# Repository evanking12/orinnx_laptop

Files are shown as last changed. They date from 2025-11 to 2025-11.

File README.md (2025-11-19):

8-Layer High-Speed PCB | NVIDIA Jetson Orin NX | Full Custom Laptop Motherboard

Author: Evan King
Status:  Revision A — Routing Complete, Pre-Fabrication
Tech Stack: Altium Designer • Jetson Linux • dtc/dtcpp • LPDDR5 SoM • eDP • M.2 • DCDC/PDN

Top view:

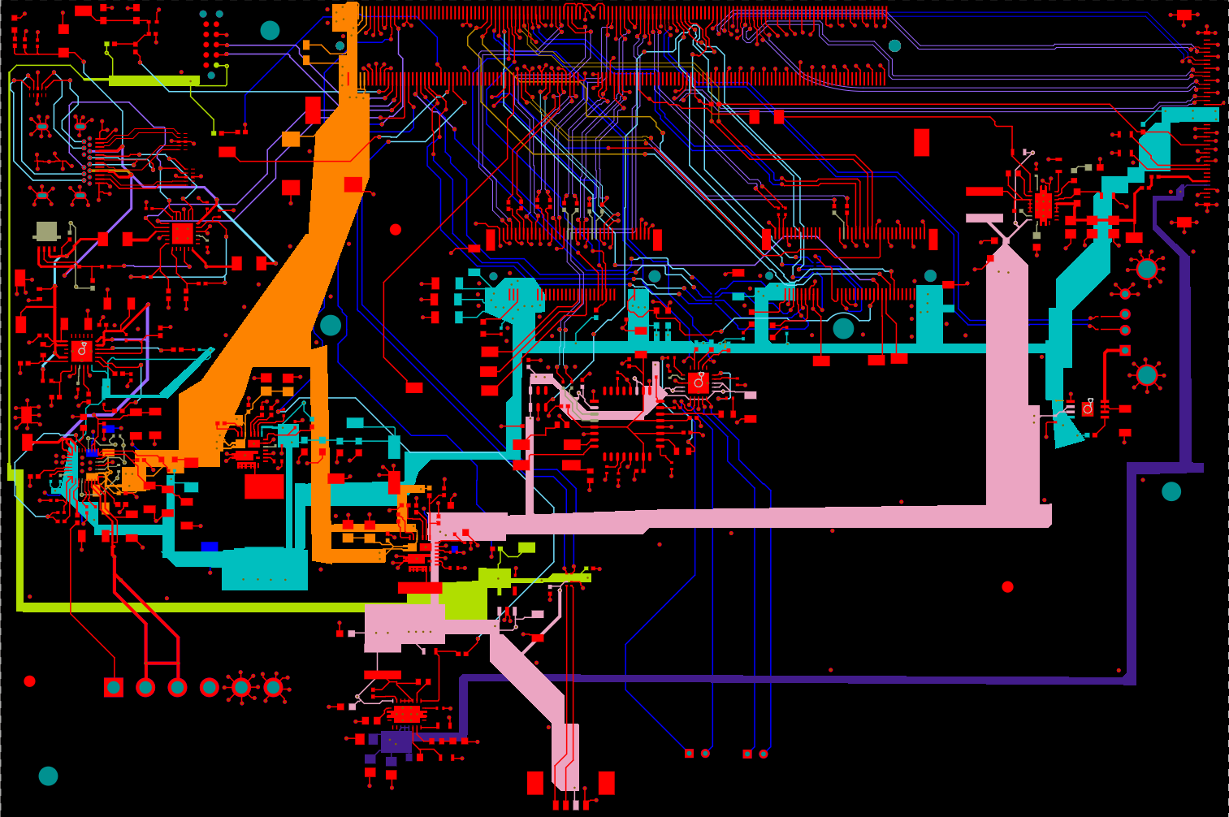
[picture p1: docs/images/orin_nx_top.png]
Orin NX Carrier Top


3D view:

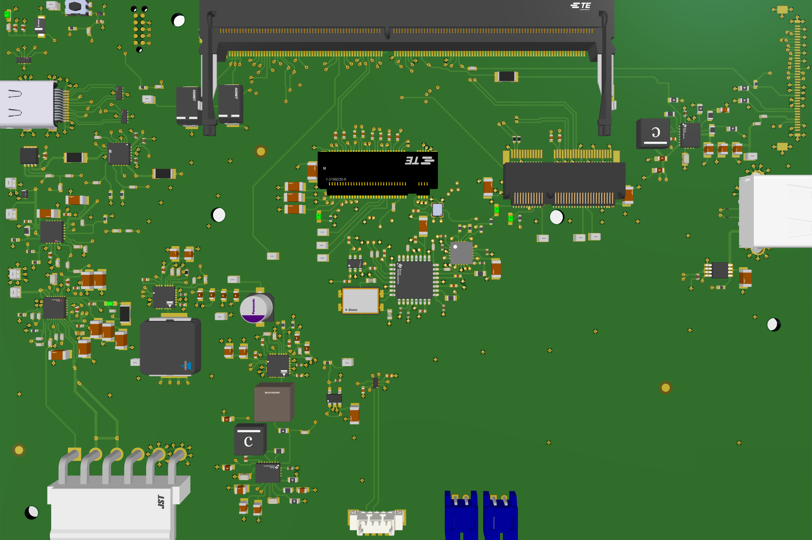
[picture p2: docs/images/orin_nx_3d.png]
Orin NX Carrier 3D


### Schematics

Full schematics (PDF):  
[Download here](docs/orin_nx_schematics.pdf)

**Overview**

This repository contains the full schematic and 8-layer PCB layout of a custom laptop motherboard designed around the NVIDIA Jetson Orin NX System-on-Module.

The goal is to build a fully custom laptop, inspired by the ANYON_E project, while focusing on:

- High-speed digital design
- Controlled impedance routing
- Embedded power delivery
- Display interface design (eDP)
- USB, UART, and M.2 storage integration
- Professional PCB workflow in Altium Designer
- Deep understanding of carrier-board engineering

**Key Specs**

- 8-layer, 1.6 mm stackup with controlled impedance (PCIe, eDP, USB)
- NVIDIA Jetson Orin NX LPDDR5 SoM
- PCIe x4 for NVMe SSD + M.2 Key E for Wi-Fi/BT
- USB2 for onboard peripherals, eDP for internal display
- Designed in Altium with full DRC/DFM checks

**Why?**
I built this project to challenge myself with something far beyond typical coursework.

I wanted to learn:

- How modern laptop motherboards are engineered
- How to design high-speed interfaces correctly
- How to read and interpret complex reference schematics
- How to design real power systems (buck converters, PDN)
- How to route differential pairs and maintain signal integrity
- How to create a board that could actually be manufactured

I learned everything through:

- Phil’s Lab (YouTube)
- Advanced Digital Hardware Design Course
- NVIDIA developer documentation
- Open-source carrier board
- Datasheets, design guides, errata sheets
- Trial, error, fixing mistakes, and learning from them

### Rev A — What Is Done

- Complete schematic
- 8-layer PCB routed
- DRCs passed
- eDP routed & impedance-matched
- Power delivery network designed
- USB2 subsystem routed
- PCIe for Wi-Fi/BT and SSD
- Project compiles cleanly in Altium

### Next Steps

- Fabrication and assembly
- Bring-up and power sequencing validation
- High-speed interface validation (PCIe, eDP, USB)

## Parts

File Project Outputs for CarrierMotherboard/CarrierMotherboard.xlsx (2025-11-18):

Comment | Description | Designator | Footprint | LibRef | Quantity
100uF | CAP TANT POLY 100UF 25V 2917 | C1, C2 | FP-T521D107M025ATE040-MFG | CMP-03016-000026-1 | 2
100nF | Chip Multilayer Ceramic Capacitors for General Purpose, 0402, 0.10uF, X7R, 15%, 10%, 50V | C101, C404, C603, C604, C607, C610, C623, C706, C707 | FP-GRM155-0_05-IPC_B | CMP-2008-04639-2 | 9
220n | Multilayer Ceramic Capacitors 220nF ±10% 16V X7R SMD 0402 | C102, C103, C106, C107, C108, C109, C110, C111, C112, C113 | FP-C1005-050-0_05-IPC_B | CMP-08246-005722-1 | 10
10μF | Chip Multilayer Ceramic Capacitors for General Purpose, 1206, 10uF, X7R, 15%, 10%, 25V | C104, C105, C114, C115, C116, C117, C501, C505, C507, C509, C516, C517, C518, C519, C520, C521, C522, C523, C524, C525, C708, C711, C901, C920 | FP-GRM31C-0_2-e0_3_0_8-MFG | CMP-06035-005515-1 | 24
22u | Cap Ceramic 22uF 16V X5R ±20% Pad SMD 0603 +85°C T/R | C301, C302, C616, C618, C619, C621, C626, C628, C630, C632 | FP-CL10-IPC_B | CMP-13271-002755-1 | 10
0.1 µF | Chip Multilayer Ceramic Capacitors for General Purpose, 0402, 0.10uF, X7R, 15%, 10%, 50V | C303, C502, C503, C510, C514, C515, C703, C902, C903, C905, C906, C907, C908, C909, C910 | FP-GRM155-0_05-IPC_B | CMP-06035-003750-1 | 15
1µF | CAP CER 1UF 10V X5R 0402 | C304, C401, C402, C403, C606, C611, C709, C710, C904, C911, C912, C918, C919 | FP-GRM15-0_1-MFG | CMP-2008-04556-2 | 13
22nf |  | C305 | CAPC1608X90X35ML10T15 | CMP-2006-02910-1 | 1
3.9n | Chip Multilayer Ceramic Capacitors for General Purpose, 0603, 3900pF, C0G, 30ppm/°C, 5%, 50V | C306 | FP-GRM188-0_1-e0_2_0_5-IPC_B | CMP-06035-027218-1 | 1
22u 25v | Chip Multilayer Ceramic Capacitors for General Purpose, 0805, 22uF, X5R, 15%, 20%, 25V | C307, C308, C309, C315, C316, C317, C601, C602, C608, C609 | FP-GRM21B-0_2-e0_2_0_7-IPC_B | CMP-2007-03222-3 | 10
 | Memory Card Connector, DDR4, SODIMM, Cam-In Locking, 260 Contacts, Copper Alloy, Cap Ceramic 22uF 16V X5R ±20% Pad SMD 0603 +85°C T/R | C310, C311 | FP-CL10-IPC_B | CMP-00001-1, CMP-13271-002755-1 | 2
0.1u | Chip Multilayer Ceramic Capacitors for General Purpose, 0402, 0.10uF, X7R, 15%, 10%, 50V | C312 | FP-GRM155-0_05-IPC_B | CMP-06035-003750-1 | 1
 | CAP CER 1UF 10V X5R 0402, [NoValue] | C313, C915, C916 | FP-GRM15-0_1-MFG | CMP-2008-04556-2, [NoValue] | 3
22n |  | C314 | CAPC1608X90X35ML10T15 | CMP-2006-02910-1 | 1
 | Chip Multilayer Ceramic Capacitors for General Purpose, 0603, 3900pF, C0G, 30ppm/°C, 5%, 50V | C318 | FP-GRM188-0_1-e0_2_0_5-IPC_B | CMP-06035-027218-1 | 1
100n | Chip Multilayer Ceramic Capacitors for General Purpose, 0402, 0.10uF, X5R, 15%, 10%, 50V | C405 | FP-GRM155-0_05-IPC_B | CMP-06035-003982-1 | 1
1u | Chip Multilayer Ceramic Capacitors for General Purpose, 0402, 1.0uF, X5R, 15%, 10%, 25V | C406 | FP-GRM155-0_1-IPC_C | CMP-06035-026280-1 | 1
100nF | Chip Multilayer Ceramic Capacitors for General Purpose, 0402, 0.10uF, X7R, 15%, 10%, 25V | C504 | FP-GRM155-0_05-IPC_C | CMP-06035-003995-1 | 1
4.7nF |  | C506 | CAPC1005X55X25LL05T10 | CMP-2008-04609-1 | 1
4.7µF |  | C508 | CAPC1608X90X35NL10T15 | CMP-2006-02810-1 | 1
47nF | Chip Multilayer Ceramic Capacitors for General Purpose, 0402, 47000pF, X7R, 15%, 10%, 50V | C511, C512 | FP-GRM155-0_05-MFG | CMP-06035-009452-1 | 2
1nF | Chip Capacitor, 1 nF, +/- 10%, 50 V, -55 to 125 degC, 0402 (1005 Metric), RoHS, Tape and Reel | C513 | CAPC1005X55X25ML5T10 | CMP-1662-00017-1 | 1
4u7 | Chip Multilayer Ceramic Capacitors for General Purpose 0402 Package 0.7mm 4.7uF @ 20% 25Vdc X5S @ 22% | C605, C620 | FP-GRM155-0_2-MFG | CMP-06035-063317-1 | 2
100u | Conductive Polymer Aluminum Solid Capacitors (OS-CON) 100uF ±20% 6.3V | C633 | FP-OS-CON-SMT-B6-MFG | CMP-05428-000099-1 | 1
 |  | C913, C914 | FP-C0603C-CF-MFG |  | 2
Green | LED GREEN CLEAR CHIP SMD | D101, D102, D103 | FP-LTST-C190GKT-MFG | CMP-22017-000005-2 | 3
ESDA25P35-1U1M | TVS DIODE 22V 41V 1610 | D401 | FP-QFN_1610-MFG | CMP-12225-000030-1 | 1
SMF24A | TVS DIODE 24V 38.9V SOD123F | D402 | FP-SMF24A-MFG | CMP-08607-000108-1 | 1
Green LED | LED GREEN CLEAR CHIP SMD | D403 | FP-LTST-C190GKT-MFG | CMP-22017-000005-2 | 1
LED_GREEN | LED YLW/GREEN DIFFUSED 1608 SMD | D501 | FP-SML-D12-MFG | CMP-08952-000005-1 | 1
TPD1E0B04DPYR | TVS DIODE 3.6V 19V 2X1SON | D701 | FP-DPY0002A-MFG | CMP-04989-000020-1 | 1
TPD1E0B04DPLR | TVS DIODE 3.6V 10.1V 2X2SON | D703, D704 | FP-DPL0002A-MFG | CMP-04989-000017-1 | 2
SODIMM | Cap Ceramic 22uF 16V X5R ±20% Pad SMD 0603 +85°C T/R | J15 | FP-2309413-1-MFG | CMP-13271-002755-1 | 1
S2751-46R1 | PC TEST POINT NATURAL | J202 | FP-S2751-46R-MFG | CMP-15817-000010-1 | 1
TP_10V_OUT | 10V nominal | J300 | FP-S2751-46R-MFG | CMP-15817-000010-1 | 1
20455-040E-76 | Conn Wire to Board RCP 40 POS 0.5mm Solder RA Side Entry SMDCABLINE® T/R | J301 | IPEX_20455-040E-76 | CMP-002-00071-3 | 1
632723300011 | Conn USB 3.1 Type C RCP 24 POS 0.5mm/0.4mm Solder RA SMD/Thru-Hole 24 Terminal 1 Port T/R | J401 | 632723300011 | CMP-002-00072-1 | 1
B6PS-VH (LF)(SN) | CONN HEADER R/A 6POS 3.96MM | J501 | FP-B6PS-VH_LF_SN-MFG | CMP-17439-000282-2 | 1
TC2050-IDC-NL | Adapter Cbl Plug Of Nails 10PIN | J701 | TAG-CONNECT_TC2050-IDC-NL | CMP-002-00074-1 | 1
533980471 | CONN HEADER SMD 4POS 1.25MM | J702 | FP-533980471-MFG | CMP-04776-000105-1 | 1
292303-1 | 1 Port Right Angle Through Hole Mount Female Type A USB Connector, 4 Position, -55 to 85 degC, RoHS, Tube | J703 | TE-292303-1_V | CMP-2000-05404-1 | 1
1-2199230-6 | Card Edge Connector, Dual Side, 67 Contacts, Surface Mount, Right Angle | J902 | FP-1-2199230-6-MFG | CMP-002-00073-2 | 1
 |  | J902A | TE_21992304 |  | 1
2.2u | Fixed Inductors 2.2uH Shld 20% 9.2A 14.5mOhms AECQ2 SRF: 38MHz Test Freq: 1MHz | L301 | FP-XAL5030-222MEC-MFG | CMP-11268-000158-1 | 1
 | Fixed Inductors 2.2uH Shld 20% 9.2A 14.5mOhms AECQ2 SRF: 38MHz Test Freq: 1MHz | L302 | FP-XAL5030-222MEC-MFG | CMP-11268-000158-1 | 1
1u/20a | FIXED IND 1UH 20A 4.52 MOHM SMD | L601 | FP-SRP6050CA-MFG | CMP-07248-000017-1 | 1
0.56µH/27.5A | Commercial Inductors, High Saturation Series 0.56uH 27.5A 1.8mΩ 20% | L603 | FP-IHLP-4040DZ-FP_3_175x4-MFG | CMP-02424-000366-1 | 1
S2B-PH-K-S(LF)(SN) | Male Header, Pitch 2 mm, 1 x 2 Position, Height 4.8 mm, Tail Length 3.4 mm, -25 to 85 degC, RoHS, Bulk | P801, P802 | JST-S2B-PH-K-S_V | CMP-1755-00004-1 | 2
STL6P3LLH6 | P-channel 30 V, 0.024 Ohm typ., 6 A STripFET H6 Power MOSFET in a PowerFLAT 3.3 x 3.3 package | Q401 | TRANS_STL6P3LLH6 | CMP-013-00034-1 | 1
0R | Chip Resistor, 0 Ohm, 0.1 W, -55 to 155 degC, 0402 (1005 Metric), RoHS, Tape and Reel | R101, R102, R612 | RESC1005X40X25LL05T05 | CMP-2000-07451-1 | 3
200R | Thick Film Chip Resistors 0402 200Ω 0.0625W 1% 100ppm/°C | R104, R105 | FP-CR0402-IPC_C | CMP-2002-04898-2 | 2
200 | Thick Film Chip Resistors 0402 200Ω 0.0625W 1% 100ppm/°C | R106 | FP-CR0402-IPC_C | CMP-2002-04898-2 | 1
22.4A | RES 0 OHM JUMPER 1/4W 0603 | R201 | FP-HCJ0603-MFG | CMP-26527-000122-1 | 1
100k | RES 100K OHM 5% 1/16W 0402 | R202, R205, R312, R404, R407, R501, R502, R512, R515, R702, R703, R910 | FP-RC0402-0_4-IPC_A | CMP-2002-07913-2 | 12
100 |  | R203, R204, R206, R402, R506, R507, R508, R521, R701 | RESC1005X40X25ML05T10 | CMP-2002-07344-1 | 9
47k |  | R207 | RESC1005X40X25ML05T10 | CMP-2002-07701-1 | 1
1k | Chip Resistor, 1 KOhm, +/- 1%, 0.25 W, -55 to 155 degC, 1206 (3216 Metric), RoHS, Tape and Reel | R208, R403, R408, R514 | RESC3216X60X45ML15T20 | CMP-2100-03616-1 | 4
301k | RES Thick Film, 301kΩ, 1%, 0.1W, 100ppm/°C, 0603 | R301, R310 | FP-CRCW0603-e3-IPC_C | CMP-2000-03218-2 | 2
100k | RES SMD 100K OHM 1% 1/10W 0603 | R302, R304, R306, R313, R314 | FP-CRCW0603C-e3-MFG | CMP-02407-011574-1 | 5
18.2k | RES Thick Film, 18.2kΩ, 1%, 0.1W, 100ppm/°C, 0603 | R303 | FP-CRCW0603-e3-IPC_C | CMP-2000-02961-2 | 1
732k | RES Thick Film, 732kΩ, 1%, 0.1W, 100ppm/°C, 0603 | R305 | FP-CRCW0603-e3-IPC_B | CMP-1012-00834-2 | 1
0 |  | R307, R308, R520 | RESC1005X40X25NL05T10 | CMP-1011-00001-2 | 3
 | RES SMD 100K OHM 1% 1/10W 0603 | R311, R316, R318 | FP-CRCW0603C-e3-MFG | CMP-02407-011574-1 | 3
 | RES Thick Film, 18.2kΩ, 1%, 0.1W, 100ppm/°C, 0603 | R315 | FP-CRCW0603-e3-IPC_C | CMP-2000-02961-2 | 1
 |  | R317 | RESC1609X50X30ML10T20 |  | 1
10k |  | R401, R509, R510, R513, R516, R517, R518, R519, R610, R618, R903, R904, R905 | RESC1005X40X25LL05T10 | CMP-2002-07353-1 | 13
100k |  | R405 | RESC1005X40X25NL05T10 | CMP-2002-07343-1 | 1
22k |  | R406 | RESC1005X40X25NL05T05 | CMP-1011-00659-2 | 1
4k7 |  | R409 | RESC1005X40X25NL10T10 | CMP-2002-05217-1 | 1
22k |  | R410, R411 | RESC1005X40X25NL05T10 | CMP-2002-07517-1 | 2
274k |  | R503 | FP-AC0603-IPC_C |  | 1
1.8m | RES Thick Film, 1.78MΩ, 1%, 0.063W, 100ppm/°C, 0402 | R504 | FP-CRCW0402-e3-MFG | CMP-2002-08335-4 | 1
289k |  | R505 | RESC1005X40X25LL05T10 | CMP-1011-00786-2 | 1
3.57k |  | R511 | RESC1005X40X25ML05T10 | CMP-2002-07655-1 | 1
10k | NTC Thermistor for Temperature Sensor, 0402, 10kΩ, 1%, 0.1mA, 5V | R522 | FP-NCP15-NCU15-0_05-IPC_C | CMP-06022-000003-3 | 1
27k |  | R523 | RESC1005X40X25LL05T10 | CMP-2002-07025-1 | 1
20k | Thick Film Chip Resistors 0402 20kΩ 0.0625W 1% 100ppm/°C | R601 | FP-CR0402-IPC_A | CMP-1011-00655-3 | 1
2k7 | Thick Film Chip Resistors 0402 2.7kΩ 0.0625W 1% 100ppm/°C | R602, R908, R909 | FP-CR0402-IPC_B | CMP-2002-05009-2 | 3
499k |  | R603, R604, R607, R608 | RESC1005X40X25NL10T10 | CMP-1011-00815-2 | 4
73k2 |  | R609 | RESC1005X40X25LL10T10 | CMP-2002-05384-1 | 1
45k3 |  | R617 | RESC1005X40X25ML05T10 | CMP-2002-07692-1 | 1
27 |  | R900, R902 | RESC1005X40X25LL05T10 | CMP-2002-07055-1 | 2
50 | RES Thick Film, 50Ω, 1%, 0.1W, 100ppm/°C, 0603 | R906, R907 | FP-CRCW0603-e3-MFG | CMP-2000-03436-2 | 2
 | RES ARRAY 4 RES ZERO OHM 0502 | RN101 | FP-EXB-18V-MFG | CMP-05421-000001-1 | 1
EXB-18VR000X | RES ARRAY 4 RES ZERO OHM 0502 | RN104 | FP-EXB-18V-MFG | CMP-05421-000001-1 | 1
KMR211NGLFS | Switch Tactile N.O. SPST Round Button Gull Wing 0.05A 32VDC 1VA 200000Cycle 1.2N SMD T/R | S701 | SW_KMR211NGLFS | CMP-016-00013-1 | 1
TP_W_DISABLE1 | PC TEST POINT NATURAL | TP2 | FP-S2751-46R-MFG | CMP-15817-000010-1 | 1
TP_W_DISABLE2 | PC TEST POINT NATURAL | TP3 | FP-S2751-46R-MFG | CMP-15817-000010-1 | 1
TP_UART_WAKE# | PC TEST POINT NATURAL | TP4 | FP-S2751-46R-MFG | CMP-15817-000010-1 | 1
TP_M2_M_ALERT# | PC TEST POINT NATURAL | TP5 | FP-S2751-46R-MFG | CMP-15817-000010-1 | 1
TP_M2_M_SMB_DATA | PC TEST POINT NATURAL | TP6 | FP-S2751-46R-MFG | CMP-15817-000010-1 | 1
TP_M2_M_SMB_CLK | PC TEST POINT NATURAL | TP7 | FP-S2751-46R-MFG | CMP-15817-000010-1 | 1
 | PC TEST POINT NATURAL | TP8, TP9 | FP-S2751-46R-MFG | CMP-15817-000010-1 | 2
GND | PC TEST POINT NATURAL | TP500, TP503, TP505 | FP-S2751-46R-MFG | CMP-15817-000010-1 | 3
TP_VSYS_IN | PC TEST POINT NATURAL | TP501 | FP-S2751-46R-MFG | CMP-15817-000010-1 | 1
TP_INJECT_VOLT | PC TEST POINT NATURAL | TP502 | FP-S2751-46R-MFG | CMP-15817-000010-1 | 1
TP_SYS_IN | PC TEST POINT NATURAL | TP504 | FP-S2751-46R-MFG | CMP-15817-000010-1 | 1
TP_3V3_OUT | PC TEST POINT NATURAL | TP603 | FP-S2751-46R-MFG | CMP-15817-000010-1 | 1
TP | PC TEST POINT NATURAL | TP700 | FP-S2751-46R-MFG | CMP-15817-000010-1 | 1
TP_1V8_LDO | PC TEST POINT NATURAL | TP701 | FP-S2751-46R-MFG | CMP-15817-000010-1 | 1
TPS61088RHLT | IC REG BOOST ADJ 10A 20VQFN | U301 | FP-RHL0020A-MFG | CMP-04918-000117-1 | 1
 | IC REG BOOST ADJ 10A 20VQFN | U302 | FP-RHL0020A-MFG | CMP-04918-000117-1 | 1
STUSB4500QTR | 4.1V~22V USB 2.0 I2C Controllers Interface ICs STUSB45 Controller 24-VFQFN Exposed Pad | U401 | FP-QFN-24-EP_4x4-MFG | CMP-12113-000003-3 | 1
TPD4E05U06QDQARQ1 | TVS DIODE 5.5V 14V 10USON | U402, U403, U404 | FP-DQA0010A-MFG | CMP-04985-000004-1 | 3
TPS26630RGET | POWER MANAGEMENT | U501 | FP-RGE0024H-MFG | CMP-04910-000050-1 | 1
BQ25792RQMR | I2C CONTROLLED, 5-A, 1-4 CELL BU | U502 | FP-RQM0029A-MFG | CMP-04911-000031-1 | 1
SIC431AED-T1-GE3 | SIC431AED-T1-GE3 IC Reg Buck Adj 24A MLP44-24 | U601, U603 | FP-T22-0442-MFG | CMP-00030-87948104-1 | 2
NTS0102GT | Line Transceiver, PDSO8, 1 X 1.95 Mm, 0.50 Mm Height, Plastic, MO-252, SOT833-1, SON-8 | U701 | PSON50P100X195X50-8N | CMP-015-00011-1 | 1
TPS7A0518PDBVT | 200mA, ultra-low-IQ, high-accuracy, low-dropout voltage regulator with enable 5-SOT-23 -40 to 125 | U702 | SOT95P280X145-5N | CMP-019-00049-1 | 1
TPS2001CDGNR | Single Channel, Current-Limited USB Power Distribution Switch, 2.9 A Current Limit, -40 to 85 degC, 8-pin MSOP-PowerPAD (DGN), Green (RoHS & no Sb/Br) | U703 | DGN0008D_L | CMP-0337-00296-2 | 1
TPS22918TDBVRQ1 | IC PWR SWITCH N-CHAN 1:1 SOT23-6 | U901 | FP-DBV0006A-IPC_C | CMP-04910-000092-1 | 1
PCM2912APJTR | IC STEREO AUD CODEC W/USB 32TQFP | U902 | FP-PJT0032A-IPC_C | CMP-04873-000003-1 | 1
TPA2016D2RTJT | 2.8-W/Ch Stereo Class-D Audio Amplifier with SmartGainTM AGC / DRC, -40 to 85 degC, 20-pin QFN (RTJ20), Green (RoHS & no Sb/Br) | U903 | RTJ0020D_V | CMP-0991-00197-2 | 1
6mhz |  | Y801 | FP-ABMM-MFG |  | 1
ECS-327MVATX-2-CN-TR3 | Oscillator, 32.768kHz, CMOS, SMD, 2.5mm x 2mm, 3.6V, 25ppm, MultiVolt ECS-327MVATX Series | Y902 | OSC_ECS-2520S25-250-FN-TR | CMP-00023-00003-1 | 1

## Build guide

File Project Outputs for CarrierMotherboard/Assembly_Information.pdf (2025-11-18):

1 | 1

## Length = 152.4mm

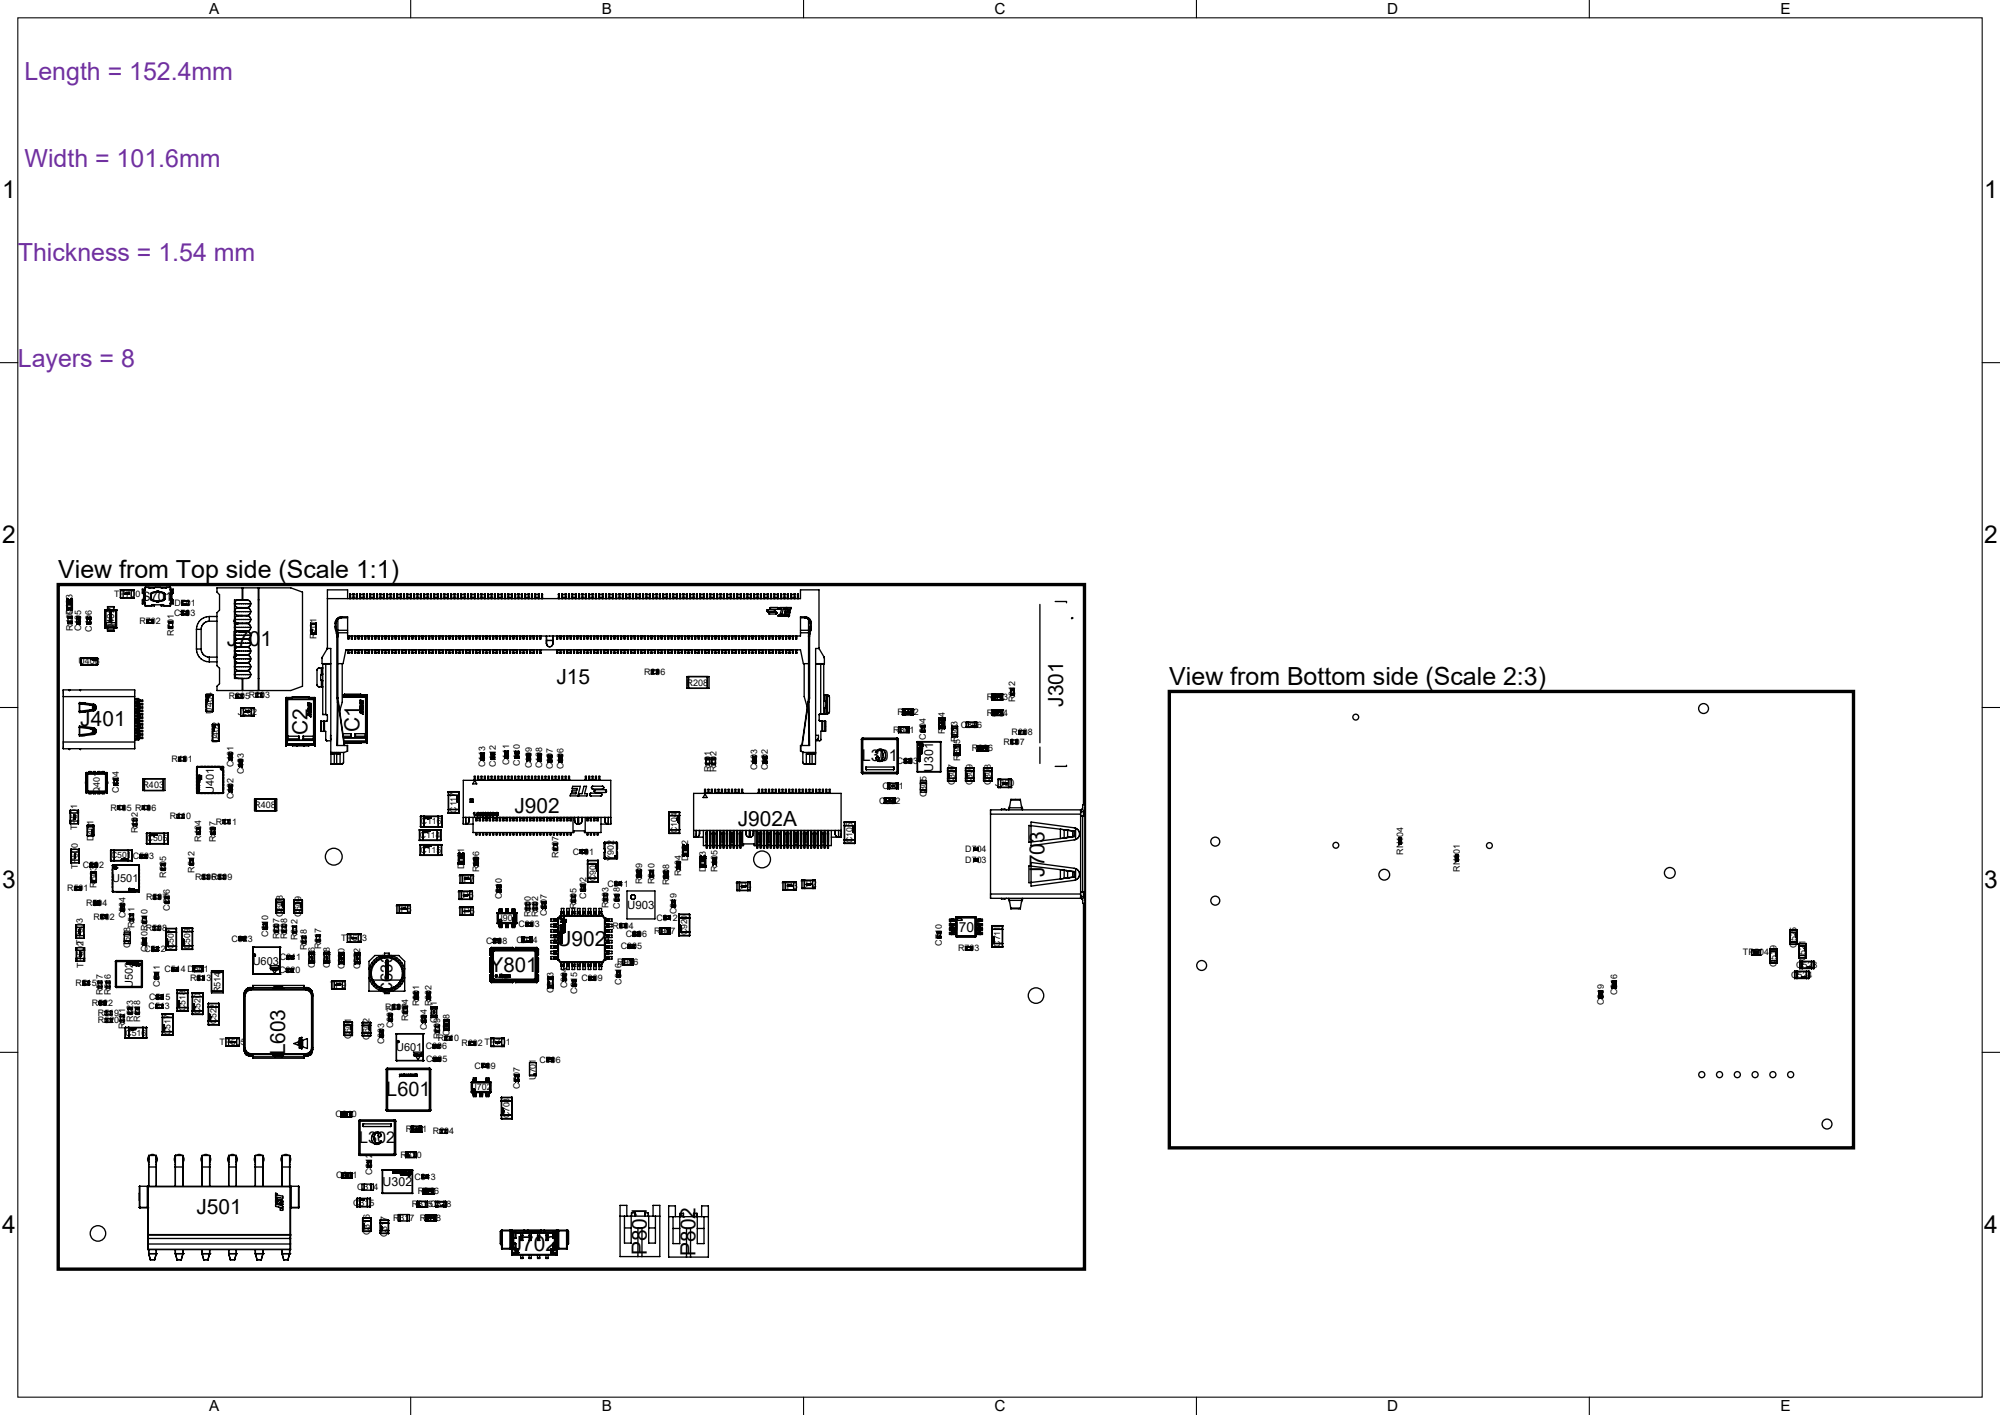
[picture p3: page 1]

View from Top side (Scale 1:1)
U501 D⁴⁰²

View from Bottom side (Scale 2:3)

1 | 1
L1-CU (Scale 1:2) | GND (Scale 1:2) | L3-CU-PWR (Scale 1:2)

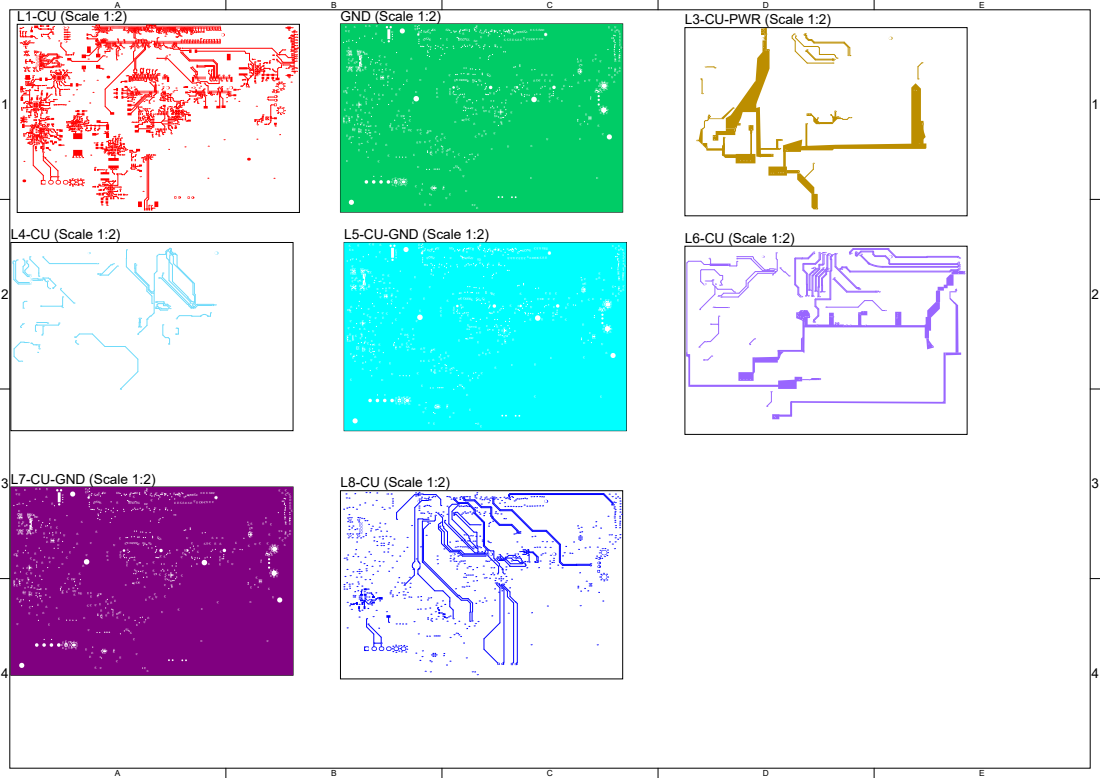
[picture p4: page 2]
L4-CU (Scale 1:2); L5-CU-GND (Scale 1:2); L6-CU (Scale 1:2); L7-CU-GND (Scale 1:2); L8-CU (Scale 1:2)

1 | 1
Material | Layer | Thickness Dielectric Material | Type | Gerber

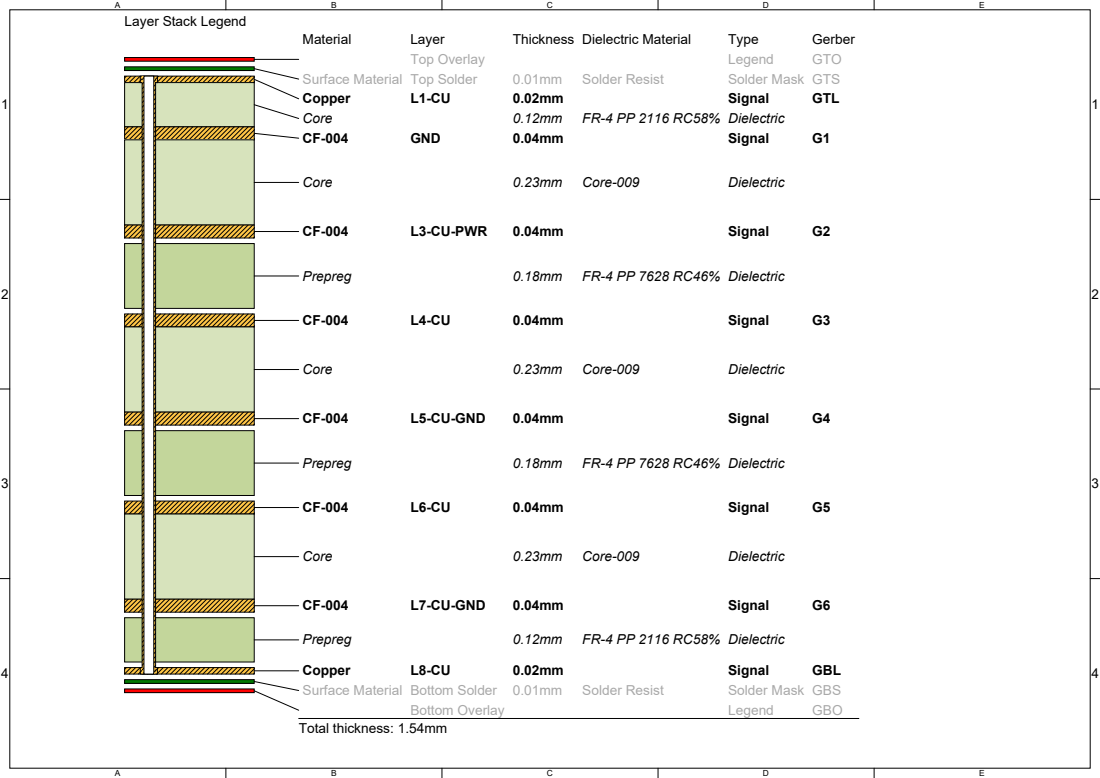
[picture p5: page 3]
Top Overlay; Legend; GTO; Surface Material Top Solder; Solder Resist; Solder Mask GTS; Copper; Signal; GTL; Core; FR-4 PP 2116 RC58% Dielectric; GND; Core-009; Dielectric; L3-CU-PWR; Prepreg; FR-4 PP 7628 RC46% Dielectric; L5-CU-GND; L7-CU-GND; GBL; Surface Material Bottom Solder 0.01mm; Solder Mask GBS; Bottom Overlay; GBO; Total thickness: 1.54mm

Layer Stack Legend

1 | 1
2 | 2
3 | 3
4 | 4

## Through-Vias only

## Impedance Id

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
## Transmission Line

Coated Microstrip
Edge-Coupled Coated Microstrip Edge-Coupled Coated Microstrip Coated Microstrip
Edge-Coupled Coated Microstrip Coated Microstrip
Offset Stripline
Edge-Coupled Offset Stripline Edge-Coupled Offset Stripline Offset Stripline
Edge-Coupled Offset Stripline Offset Stripline
Offset Stripline
Edge-Coupled Offset Stripline Edge-Coupled Offset Stripline Offset Stripline
Edge-Coupled Offset Stripline Offset Stripline
Offset Stripline
Edge-Coupled Offset Stripline Edge-Coupled Offset Stripline Offset Stripline
Edge-Coupled Offset Stripline Offset Stripline
Coated Microstrip
Edge-Coupled Coated Microstrip Edge-Coupled Coated Microstrip Coated Microstrip
Edge-Coupled Coated Microstrip Coated Microstrip

## Target Impedance

50
90
85
45
100
42.5
50
90
85
45
100
42.5
50
90
85
45
100
42.5
50
90
85
45
100
42.5
50
90
85
45
100
42.5

## Calculated Impedance

49.99
85.14
88.03
45.00
94.63
42.49
50.01
85.23
85.23
44.99
94.30
42.49
50.01
85.23
85.23
44.99
94.30
42.49
50.01
85.23
85.23
44.99
94.30
42.49
49.99
88.02
88.02
45.01
94.60
42.50

## Trace layer

L1-CU
L1-CU
L1-CU
L1-CU
L1-CU
L1-CU
L3-CU-PWR
L3-CU-PWR
L3-CU-PWR
L3-CU-PWR
L3-CU-PWR
L3-CU-PWR
L4-CU
L4-CU
L4-CU
L4-CU
L4-CU
L4-CU
L6-CU
L6-CU
L6-CU
L6-CU
L6-CU
L6-CU
L8-CU
L8-CU
L8-CU
L8-CU
L8-CU
L8-CU

## Wide Trace Width

0.21mm
0.25mm
0.25mm
0.25mm
0.21mm
0.27mm
0.13mm
0.17mm
0.17mm
0.17mm
0.13mm
0.19mm
0.13mm
0.17mm
0.17mm
0.17mm
0.13mm
0.19mm
0.13mm
0.17mm
0.17mm
0.17mm
0.13mm
0.19mm
0.22mm
0.25mm
0.25mm
0.25mm
0.21mm
0.28mm

## Narrow Trace Width

0.21mm
0.25mm
0.25mm
0.25mm
0.21mm
0.27mm
0.13mm
0.17mm
0.17mm
0.17mm
0.13mm
0.19mm
0.13mm
0.17mm
0.17mm
0.17mm
0.13mm
0.19mm
0.13mm
0.17mm
0.17mm
0.17mm
0.13mm
0.19mm
0.22mm
0.25mm
0.25mm
0.25mm
0.21mm
0.28mm

## Gap

0.30mm
0.30mm

0.30mm

0.30mm
0.30mm

0.30mm

0.30mm
0.30mm

0.30mm

0.30mm
0.30mm

0.30mm

0.30mm
0.30mm

0.30mm

## Reference layers

GND
GND
GND
GND
GND
GND
GND,L4-CU
GND,L4-CU
GND,L4-CU
GND,L4-CU
GND,L4-CU
GND,L4-CU
L3-CU-PWR,L5-CU-GND
L3-CU-PWR,L5-CU-GND
L3-CU-PWR,L5-CU-GND
L3-CU-PWR,L5-CU-GND
L3-CU-PWR,L5-CU-GND
L3-CU-PWR,L5-CU-GND
L5-CU-GND,L7-CU-GND
L5-CU-GND,L7-CU-GND
L5-CU-GND,L7-CU-GND
L5-CU-GND,L7-CU-GND
L5-CU-GND,L7-CU-GND
L5-CU-GND,L7-CU-GND
L7-CU-GND
L7-CU-GND
L7-CU-GND
L7-CU-GND
L7-CU-GND
L7-CU-GND

## Substack

Board Layer Stack
Board Layer Stack
Board Layer Stack
Board Layer Stack
Board Layer Stack
Board Layer Stack
Board Layer Stack
Board Layer Stack
Board Layer Stack
Board Layer Stack
Board Layer Stack
Board Layer Stack
Board Layer Stack
Board Layer Stack
Board Layer Stack
Board Layer Stack
Board Layer Stack
Board Layer Stack
Board Layer Stack
Board Layer Stack
Board Layer Stack
Board Layer Stack
Board Layer Stack
Board Layer Stack
Board Layer Stack
Board Layer Stack
Board Layer Stack
Board Layer Stack
Board Layer Stack
Board Layer Stack

## Clearance

0.13mm
0.13mm
0.00mm
0.13mm
0.13mm
0.13mm
0.00mm
0.00mm
0.00mm
0.13mm
0.13mm
0.13mm
0.00mm
0.00mm
0.13mm
0.13mm
0.13mm
0.13mm
0.00mm
0.00mm
0.00mm
0.13mm
0.13mm
0.13mm
0.00mm
0.00mm
0.00mm
0.13mm
0.13mm
0.13mm

## Target Tolerance

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
## Transmission Line Structure Table

Impedance Control Notes

Provide controlled impedance for all high-speed interfaces according to the “Transmission Line Structure Table” in this drawing.

Target impedances by interface:

eDP

50 Ω single-ended

100 Ω differential

PCIe

42.5 Ω single-ended (half-impedance of 85 Ω diff)

85 Ω differential

USB (USB2)

45 Ω single-ended (half-impedance of 90 Ω diff)

90 Ω differential

Impedance tolerance: ±10% for all controlled-impedance structures.

Trace widths and spacings shown in the design are nominal; the PCB manufacturer may adjust them as required to achieve the target impedances on the specified layers.

1 | 1

## View from Top side (Scale 2:3)

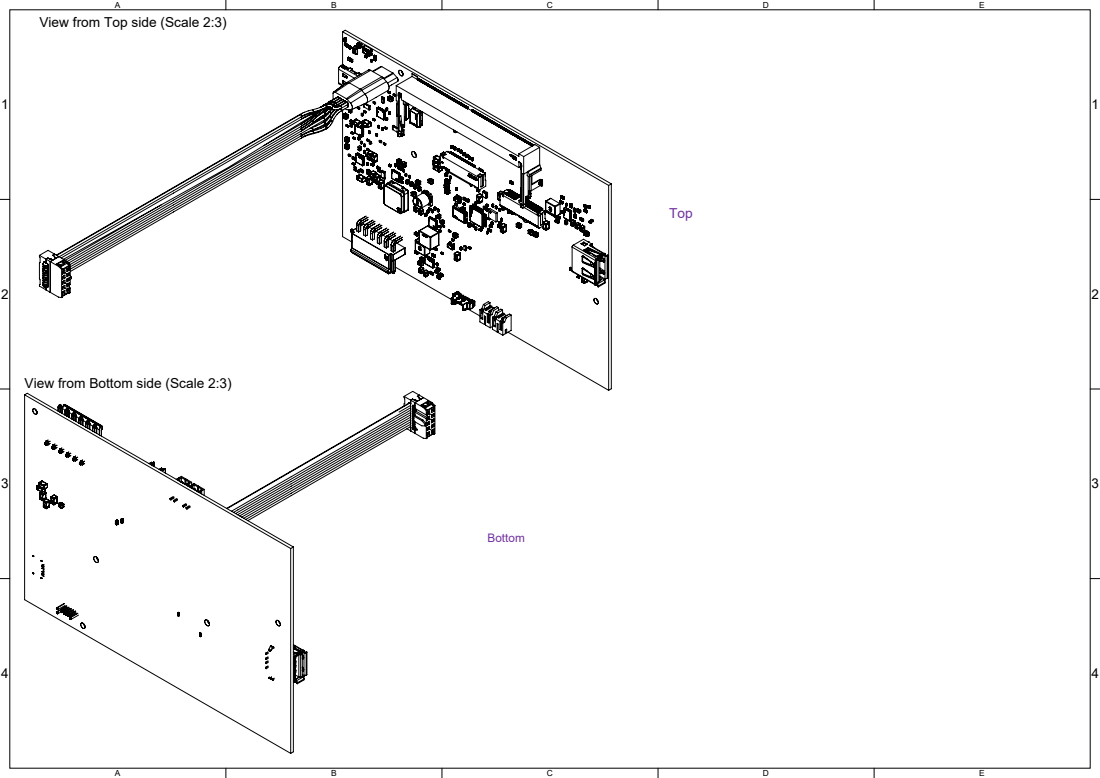
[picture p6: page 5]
Top; Bottom

View from Bottom side (Scale 2:3)

1 | 1

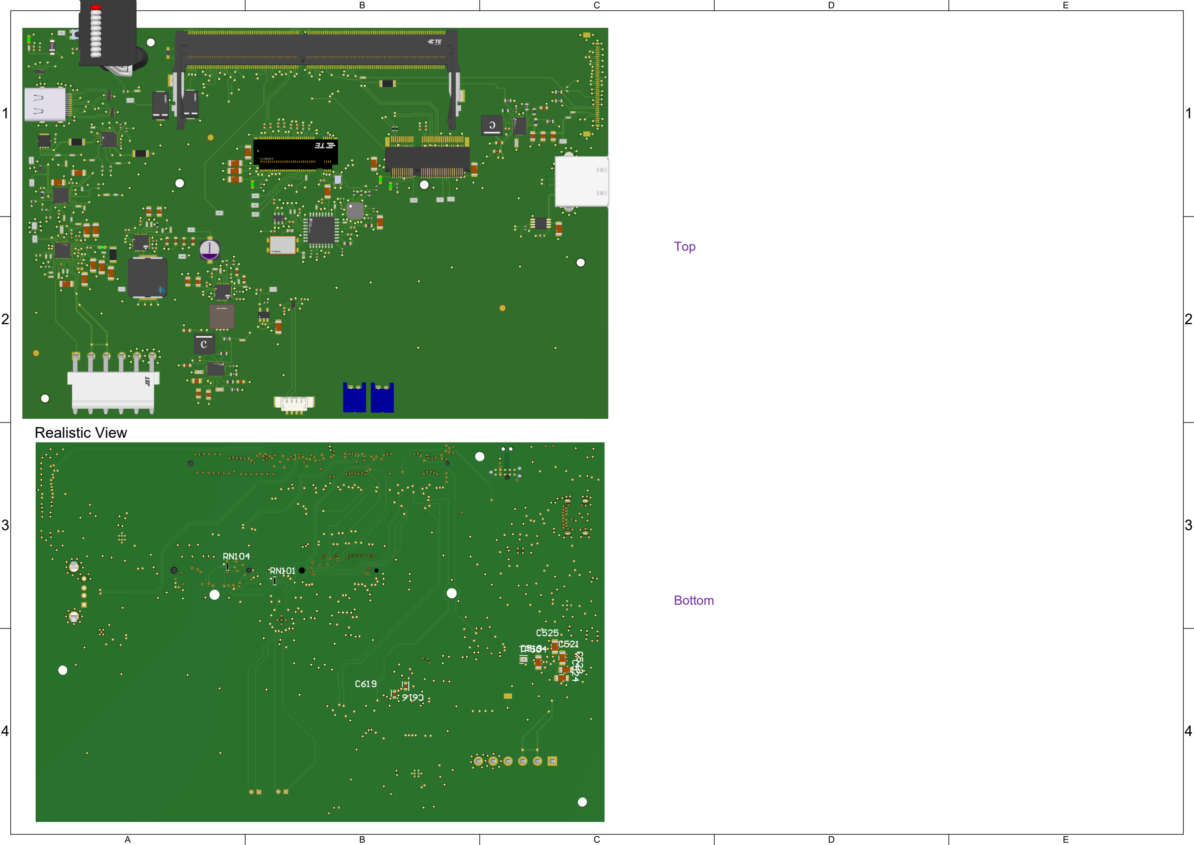
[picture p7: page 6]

2 | 2
3 | 3
4 | 4

## Realistic View

## Top

## Bottom

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
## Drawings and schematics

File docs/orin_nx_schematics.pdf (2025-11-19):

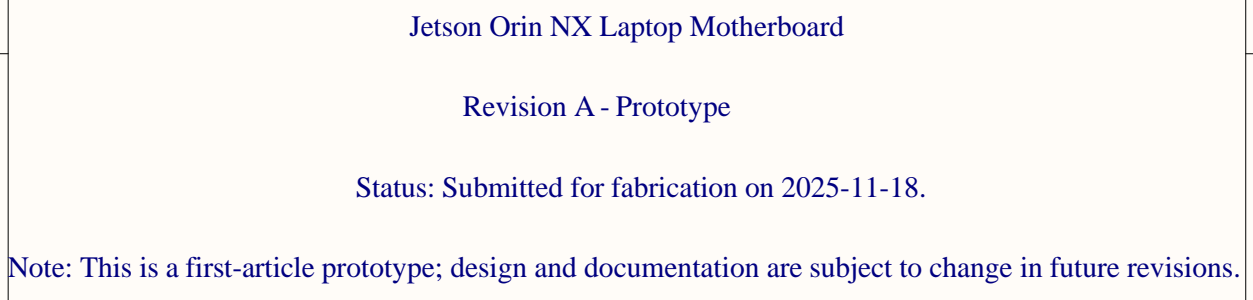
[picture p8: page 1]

Jetson Orin NX Laptop Motherboard

Status: Submitted for fabrication on 2025-11-18.

Note: This is a first-article prototype; design and documentation are subject to change in future revisions.

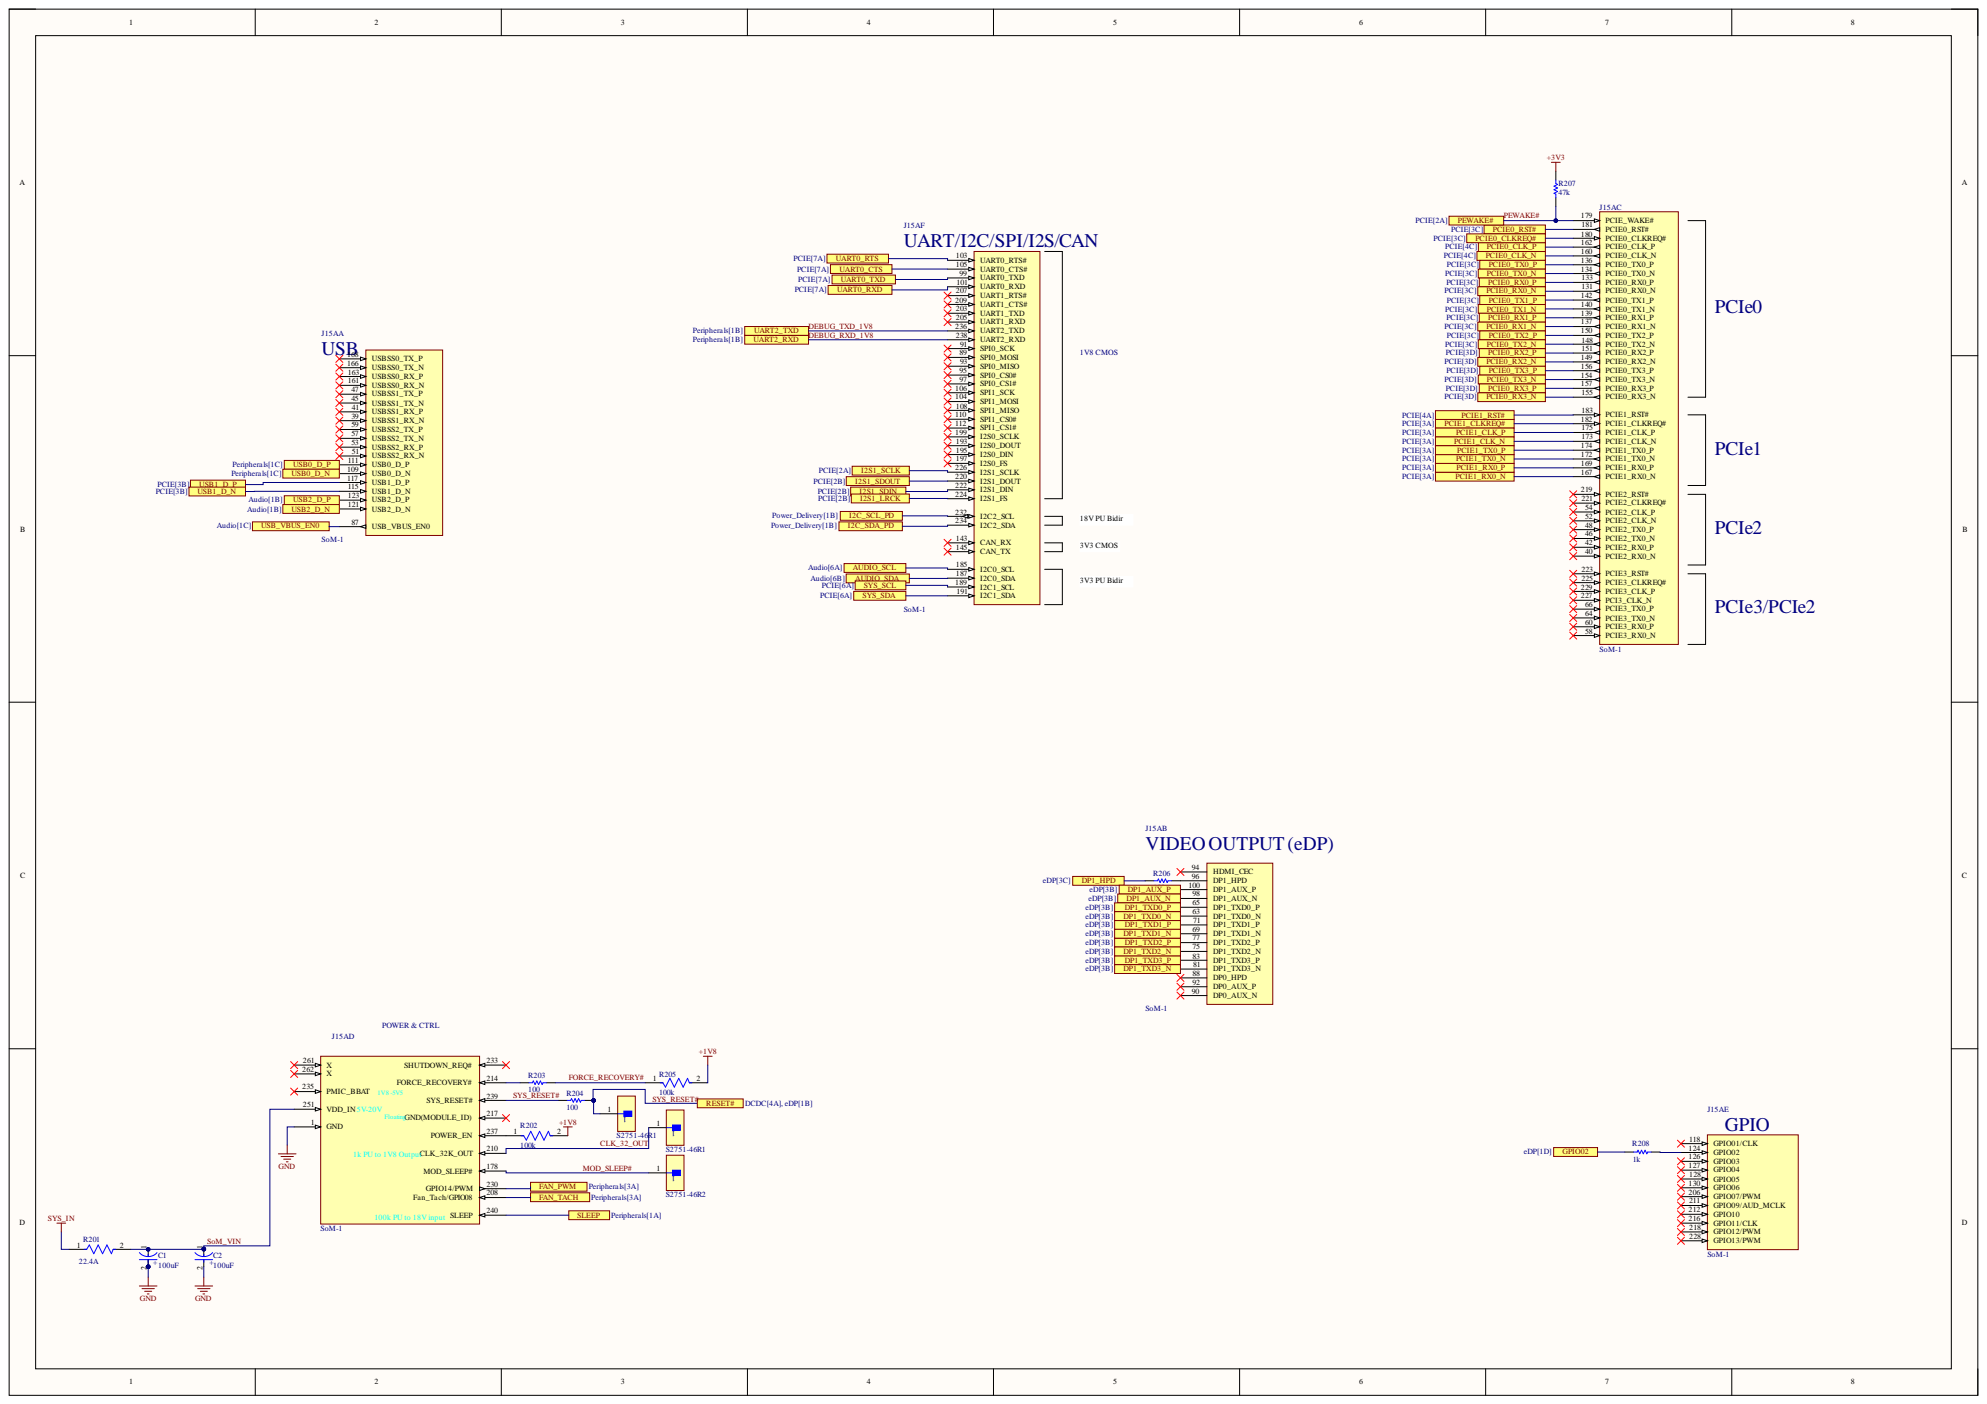
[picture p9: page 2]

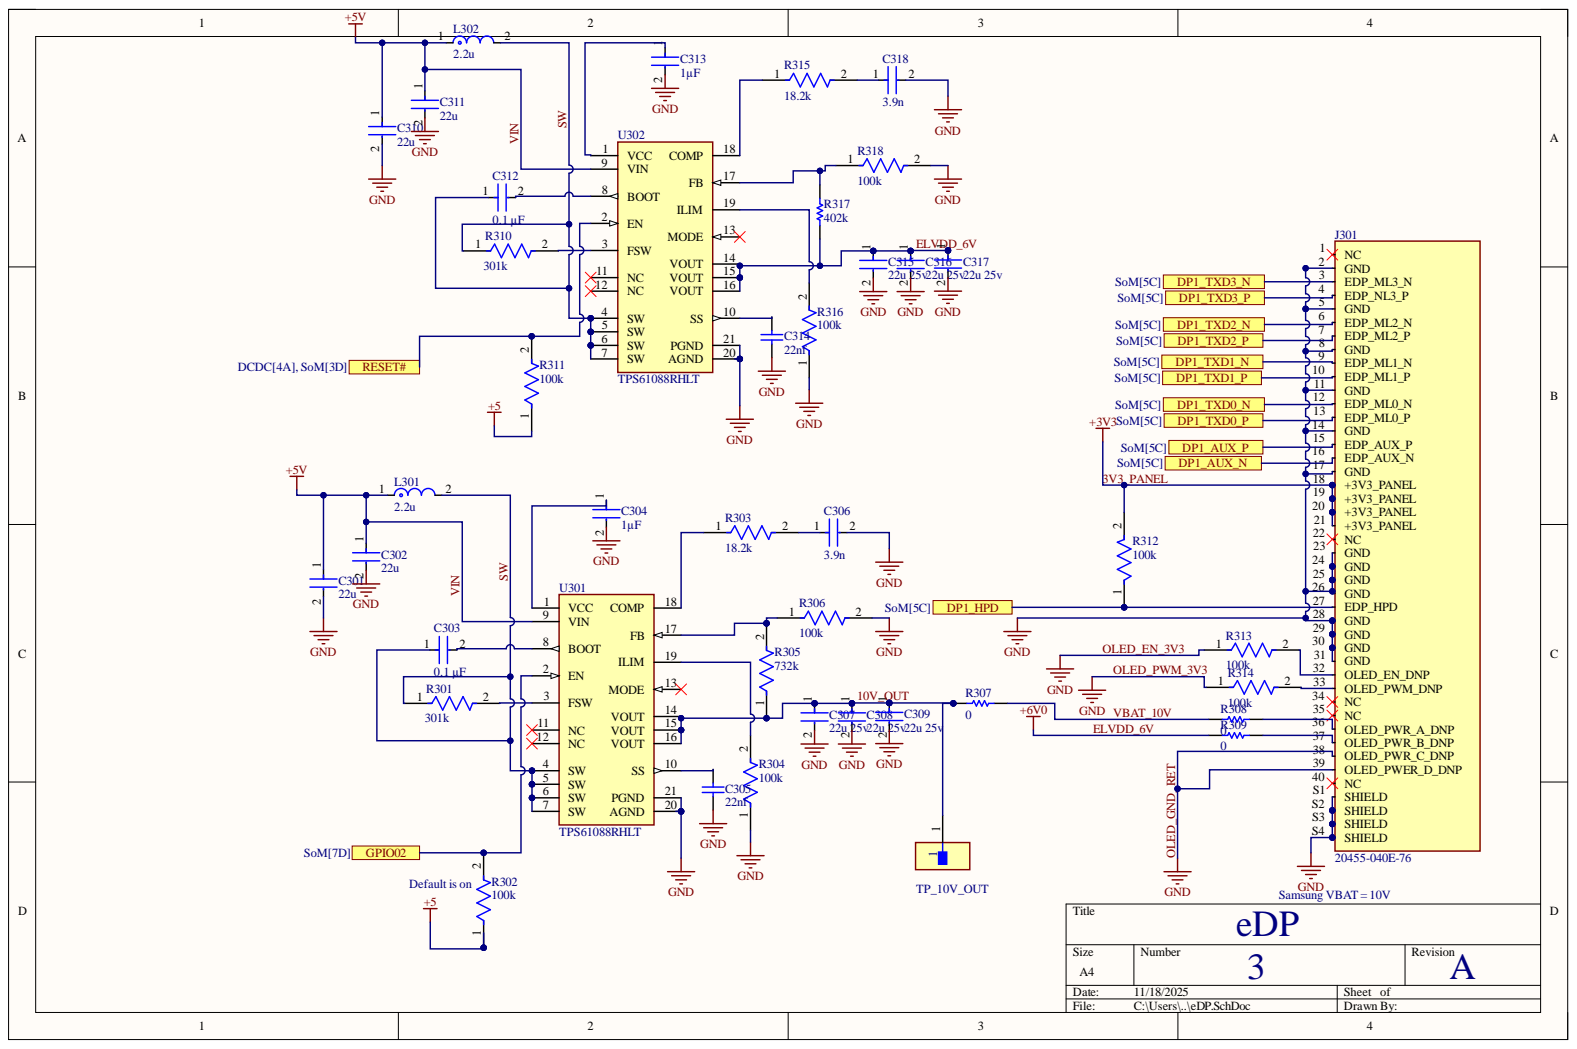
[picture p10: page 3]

BOOT 8

Size A4 | Number 3 | Revision A

Date: 11/18/2025 | Sheet of
File: C:\Users\..\eDP.SchDoc | Drawn By:

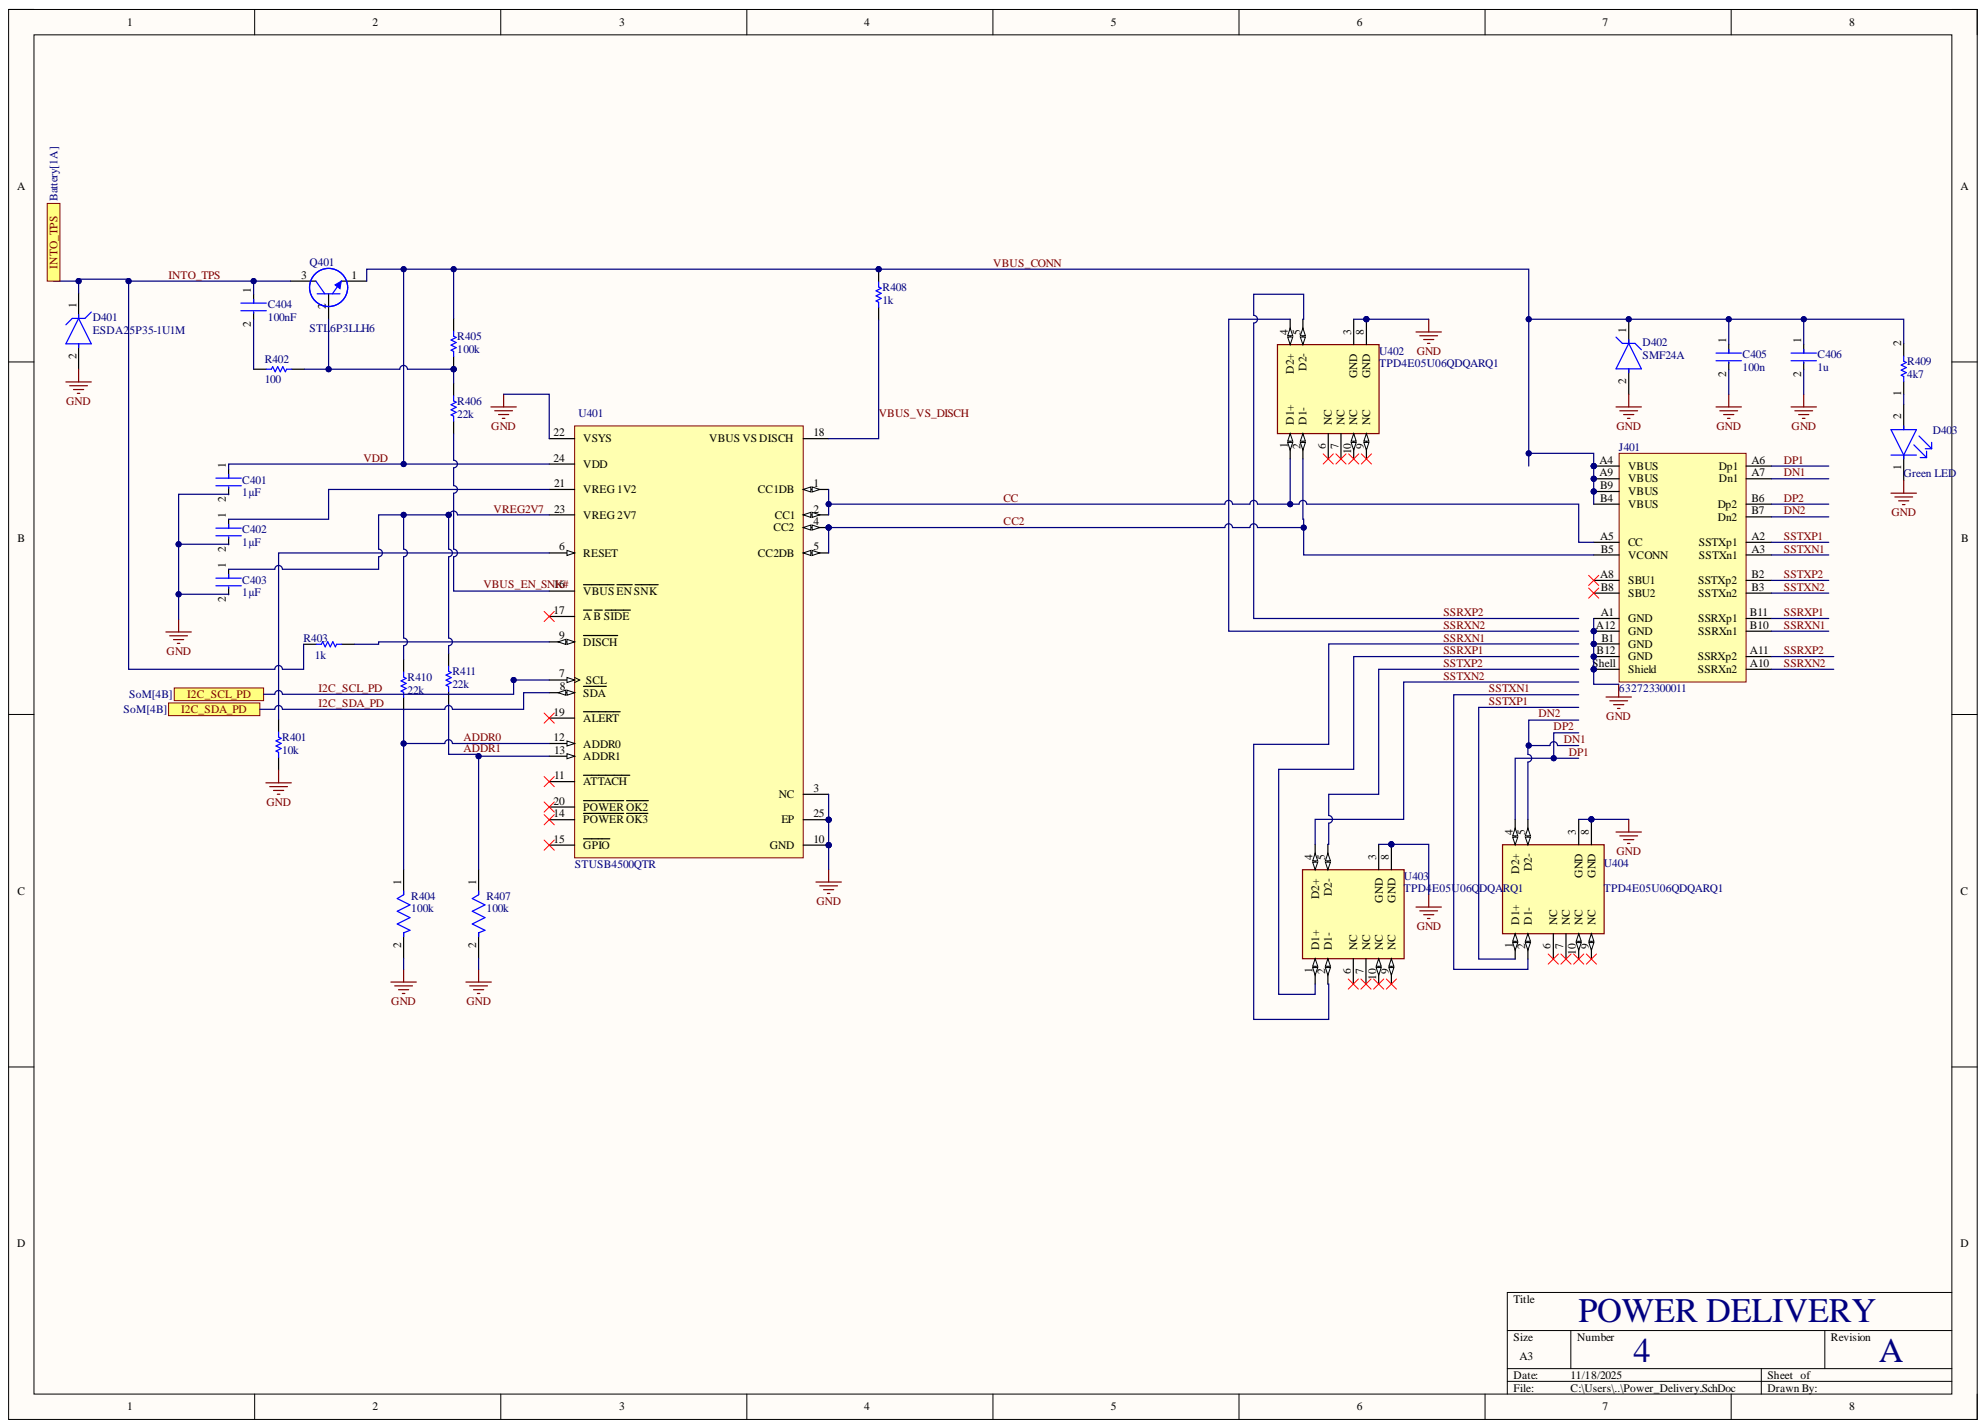
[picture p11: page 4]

A 5
B 5

S S TXP 2 | S h e l l
S S TXN 2

4 E | QAR | Q 1

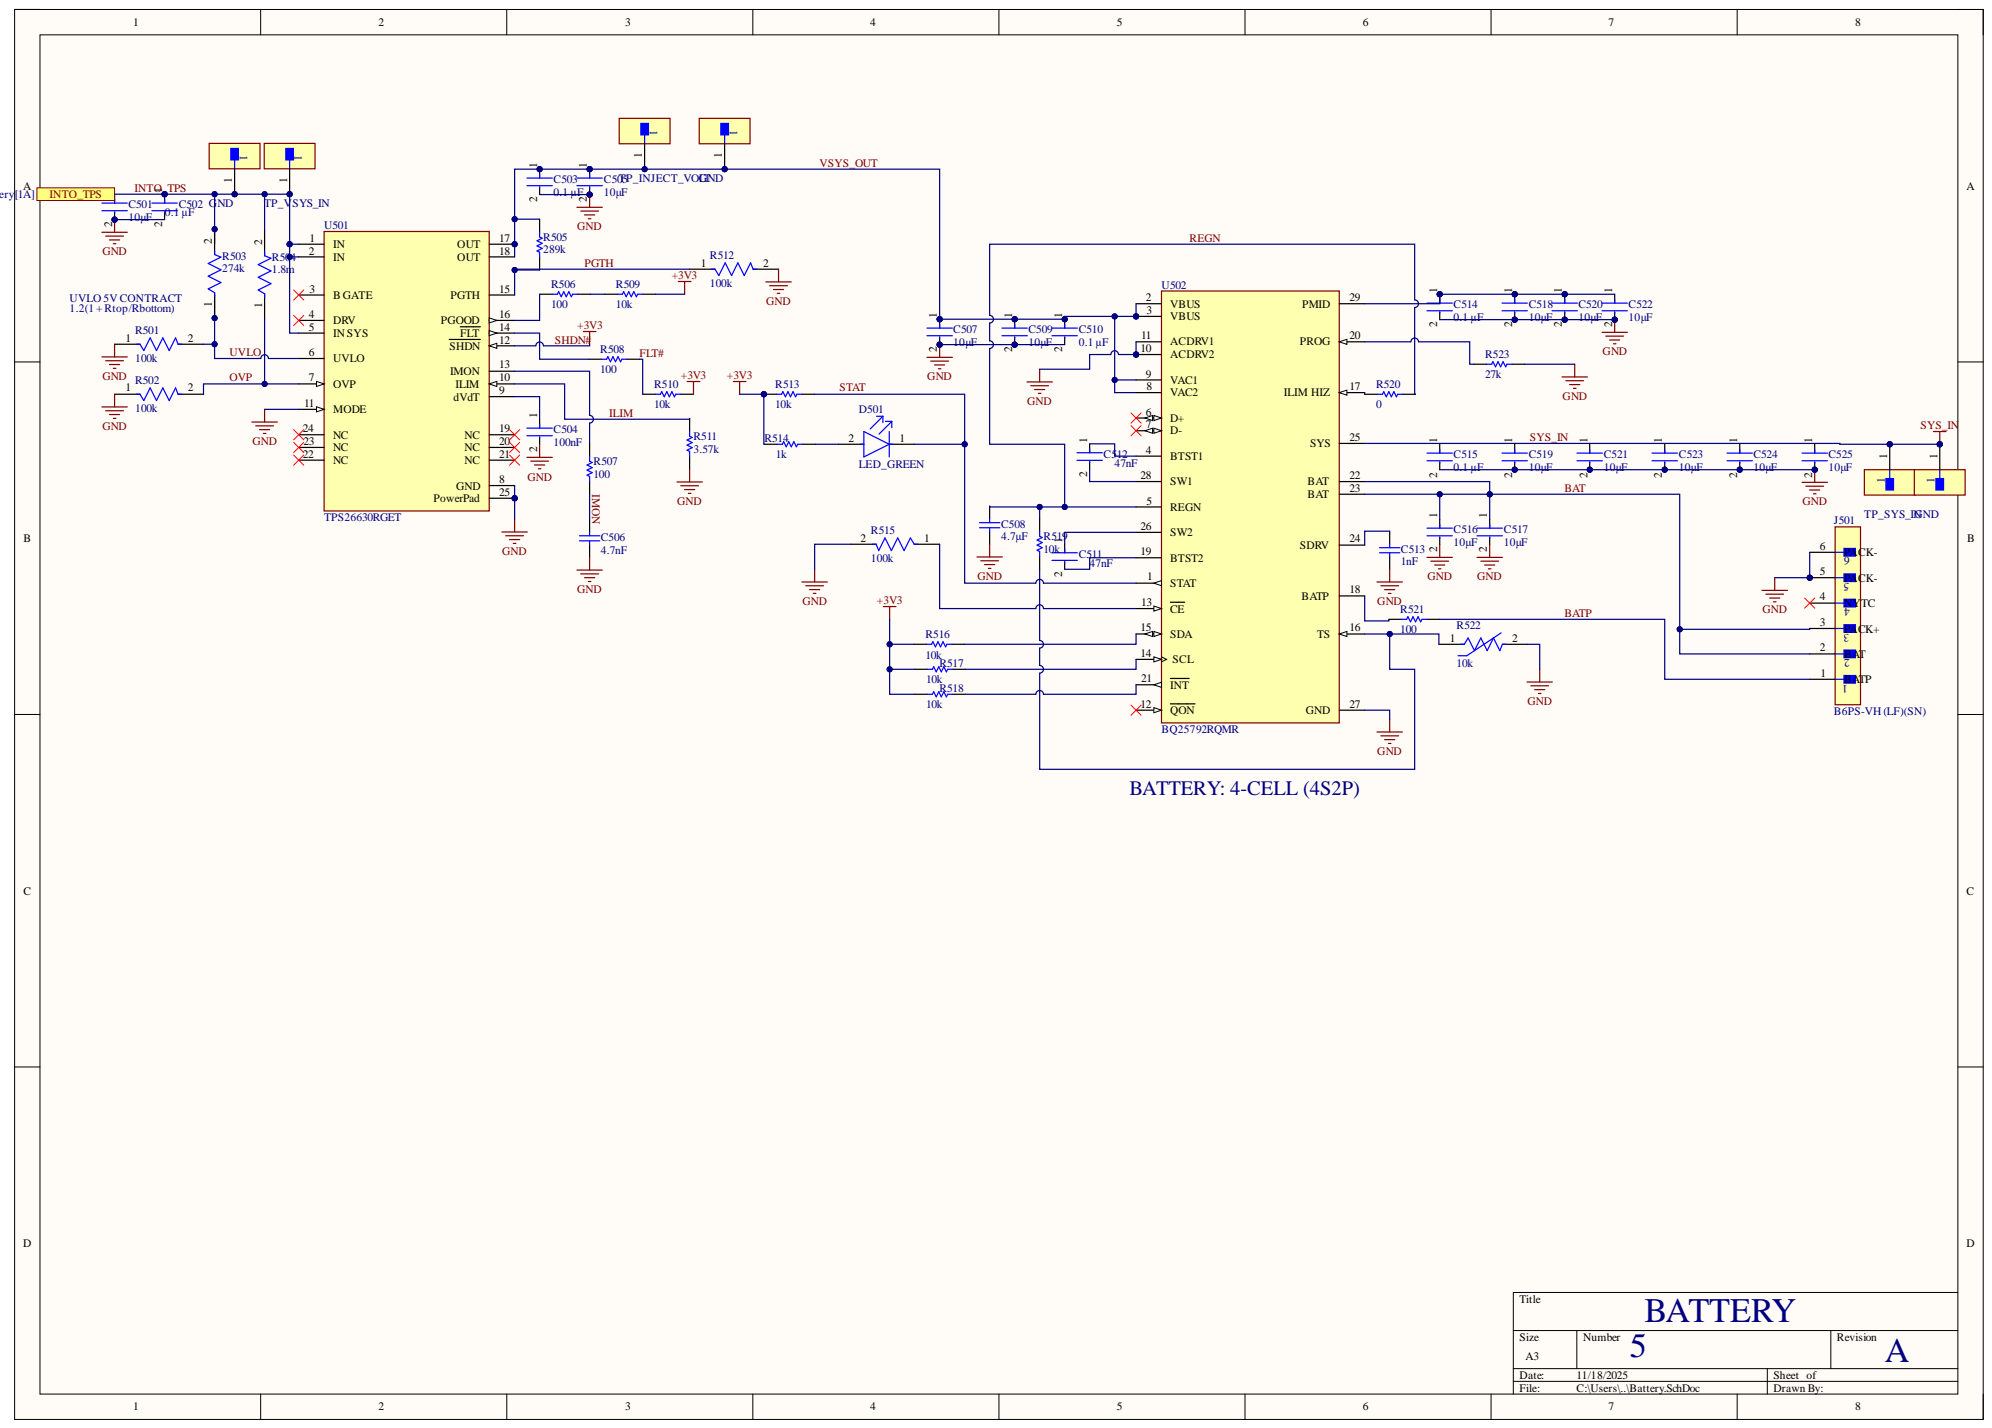
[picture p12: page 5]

5 | 1 4 | C 5 0 9 | 1 1 | A C D RV 1 P R O G A C D RV 2 VA C 1 VA C 2 I LIM H I Z D + D -S Y S B T S T 1 S W 1 B AT B AT R E GN S W2 S D RV B T S T 2 S TAT B AT P C E S D A T S S C L I N T Q O N G ND | 2 0
6 | 1 2 | S H D N#

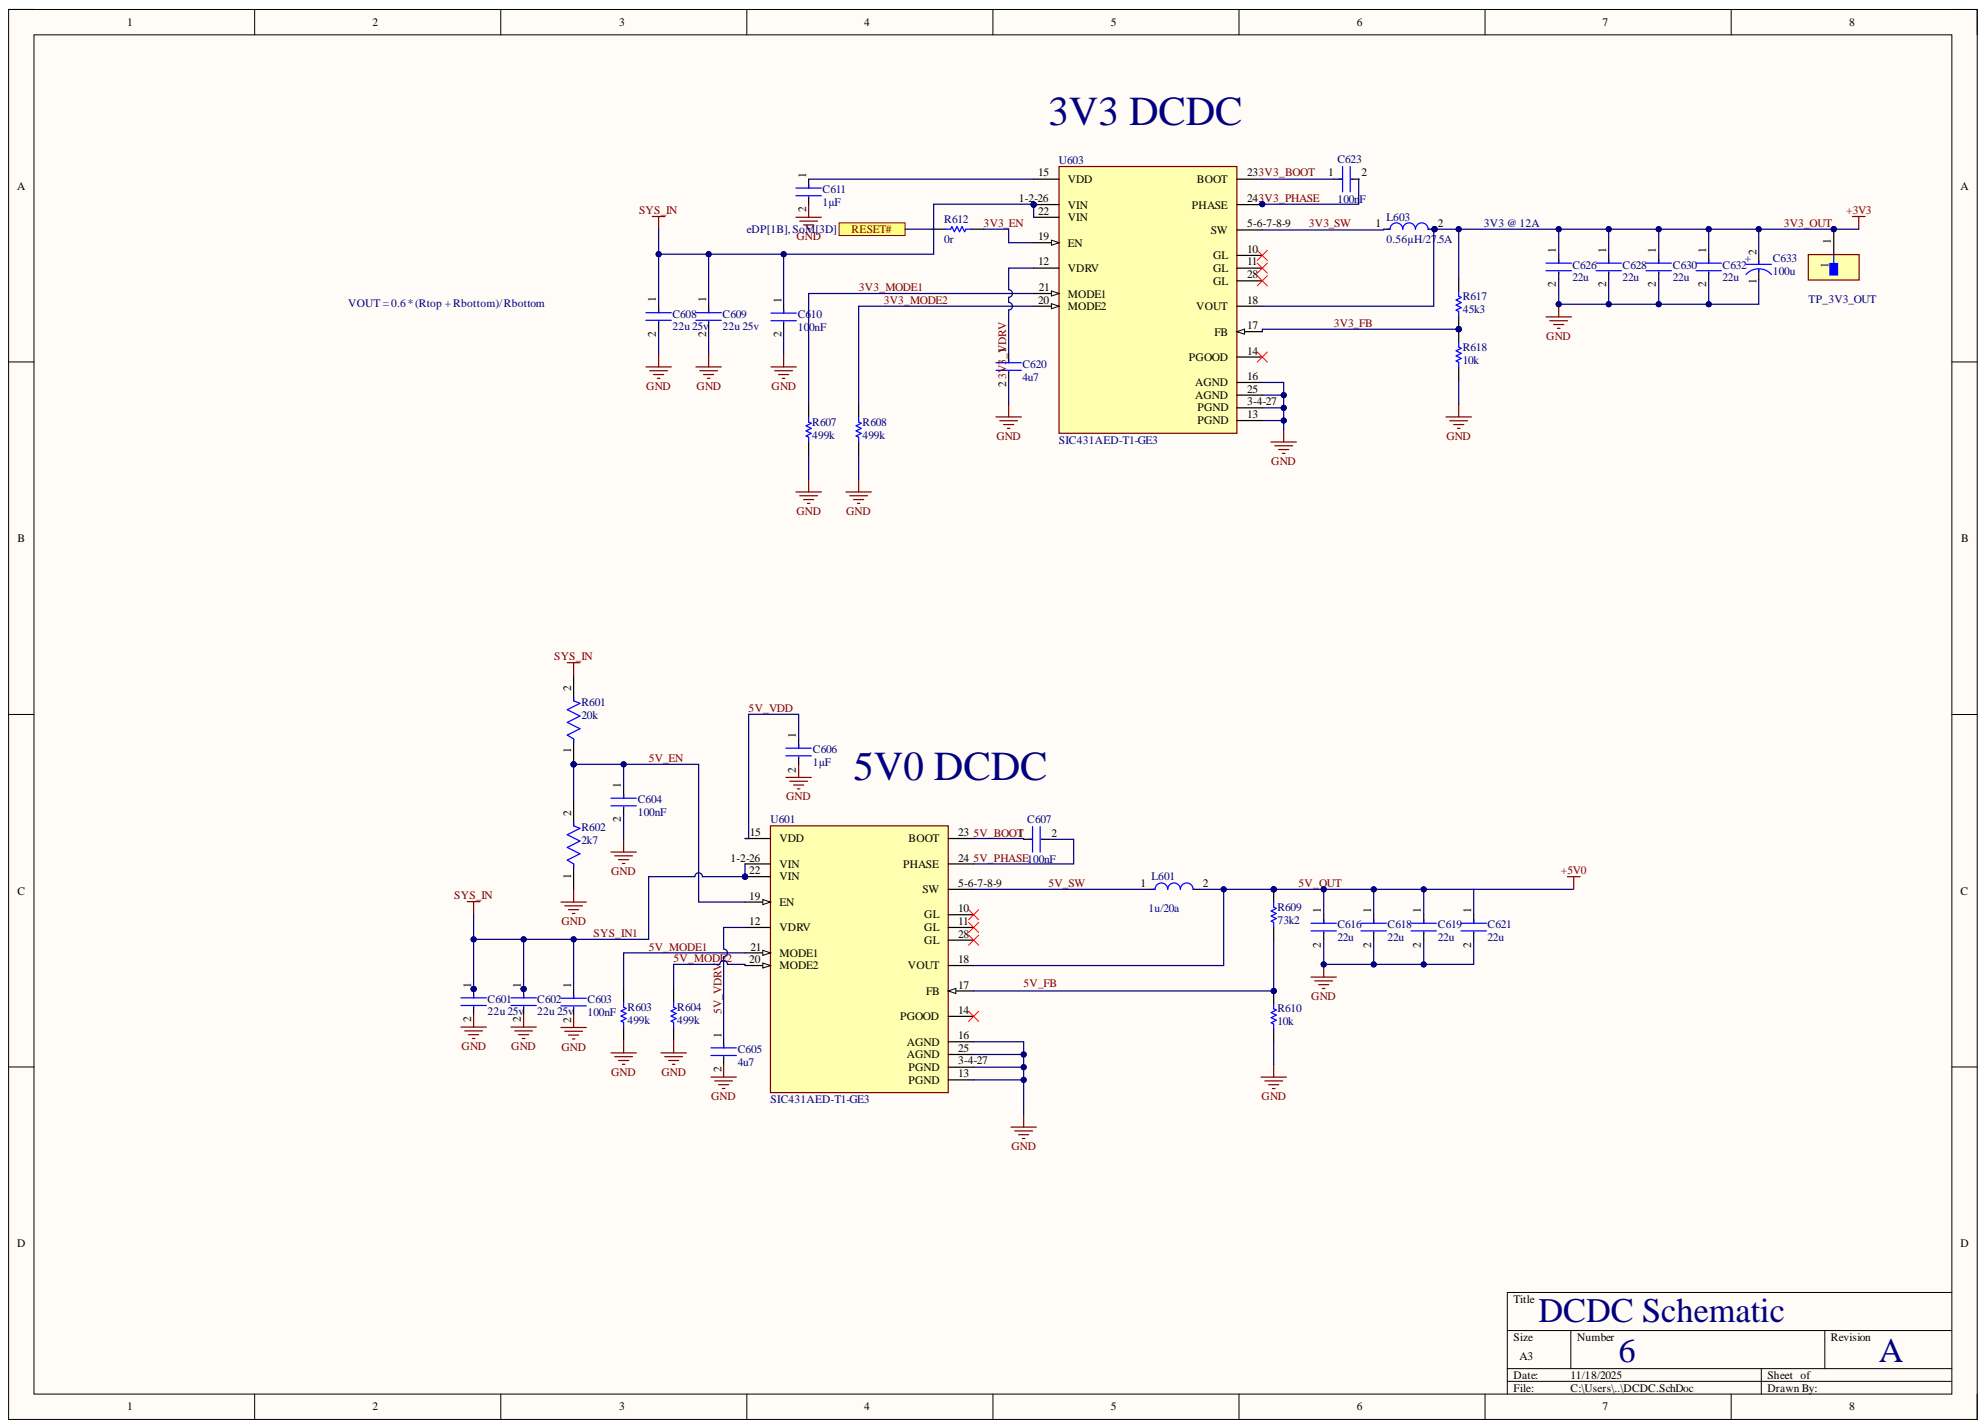
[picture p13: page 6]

3V3_MODE2 | MODE2 20

SYS_IN1 | | EN 19

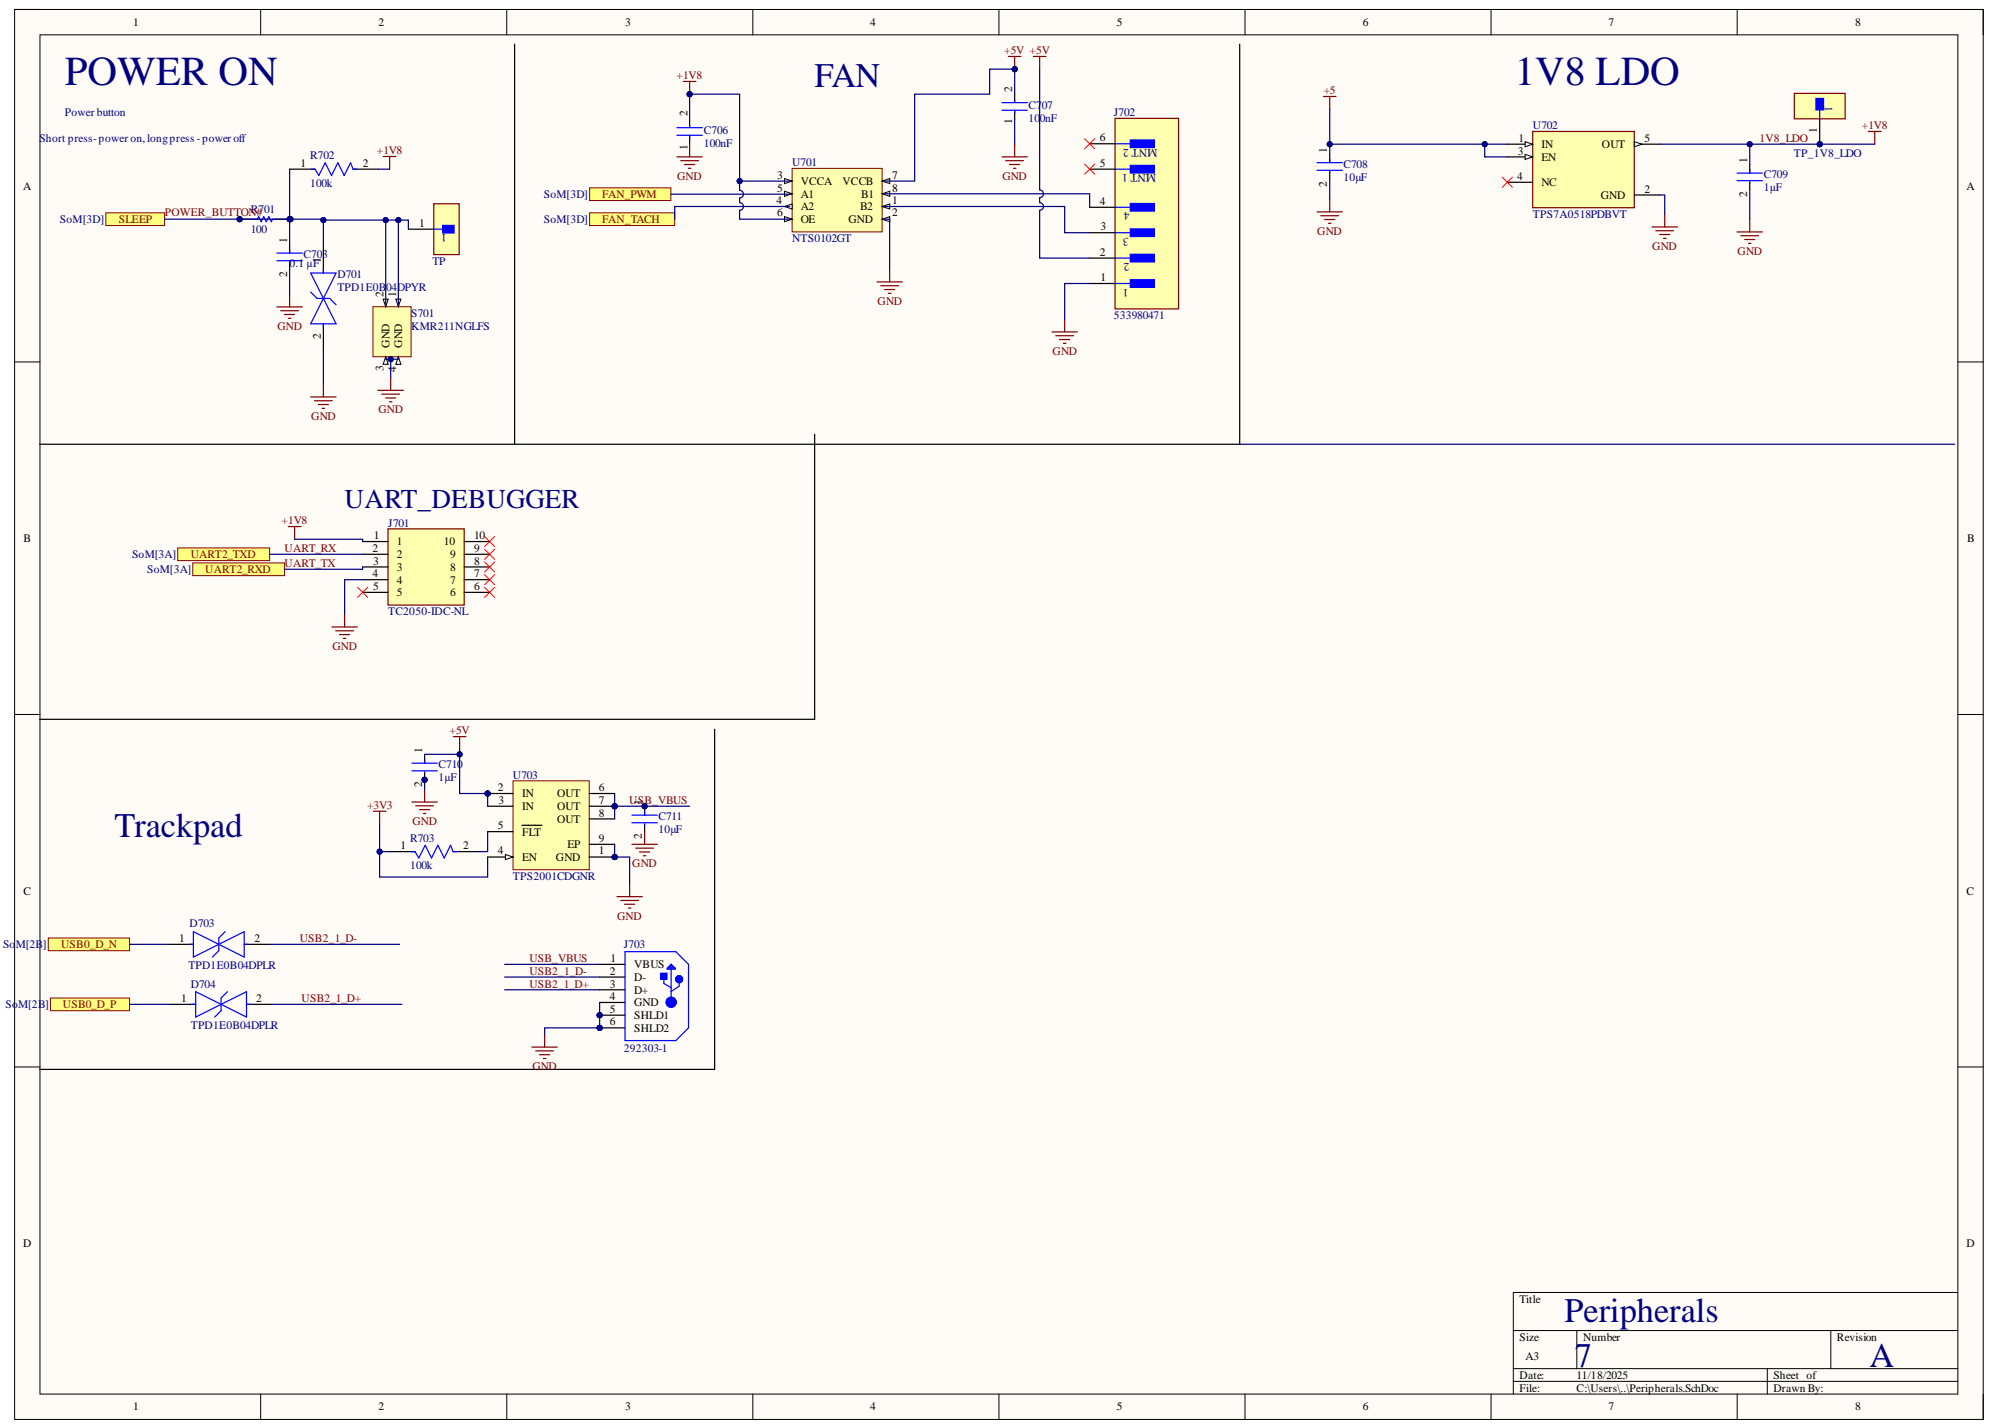
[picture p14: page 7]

Short press- power on, long press- power off

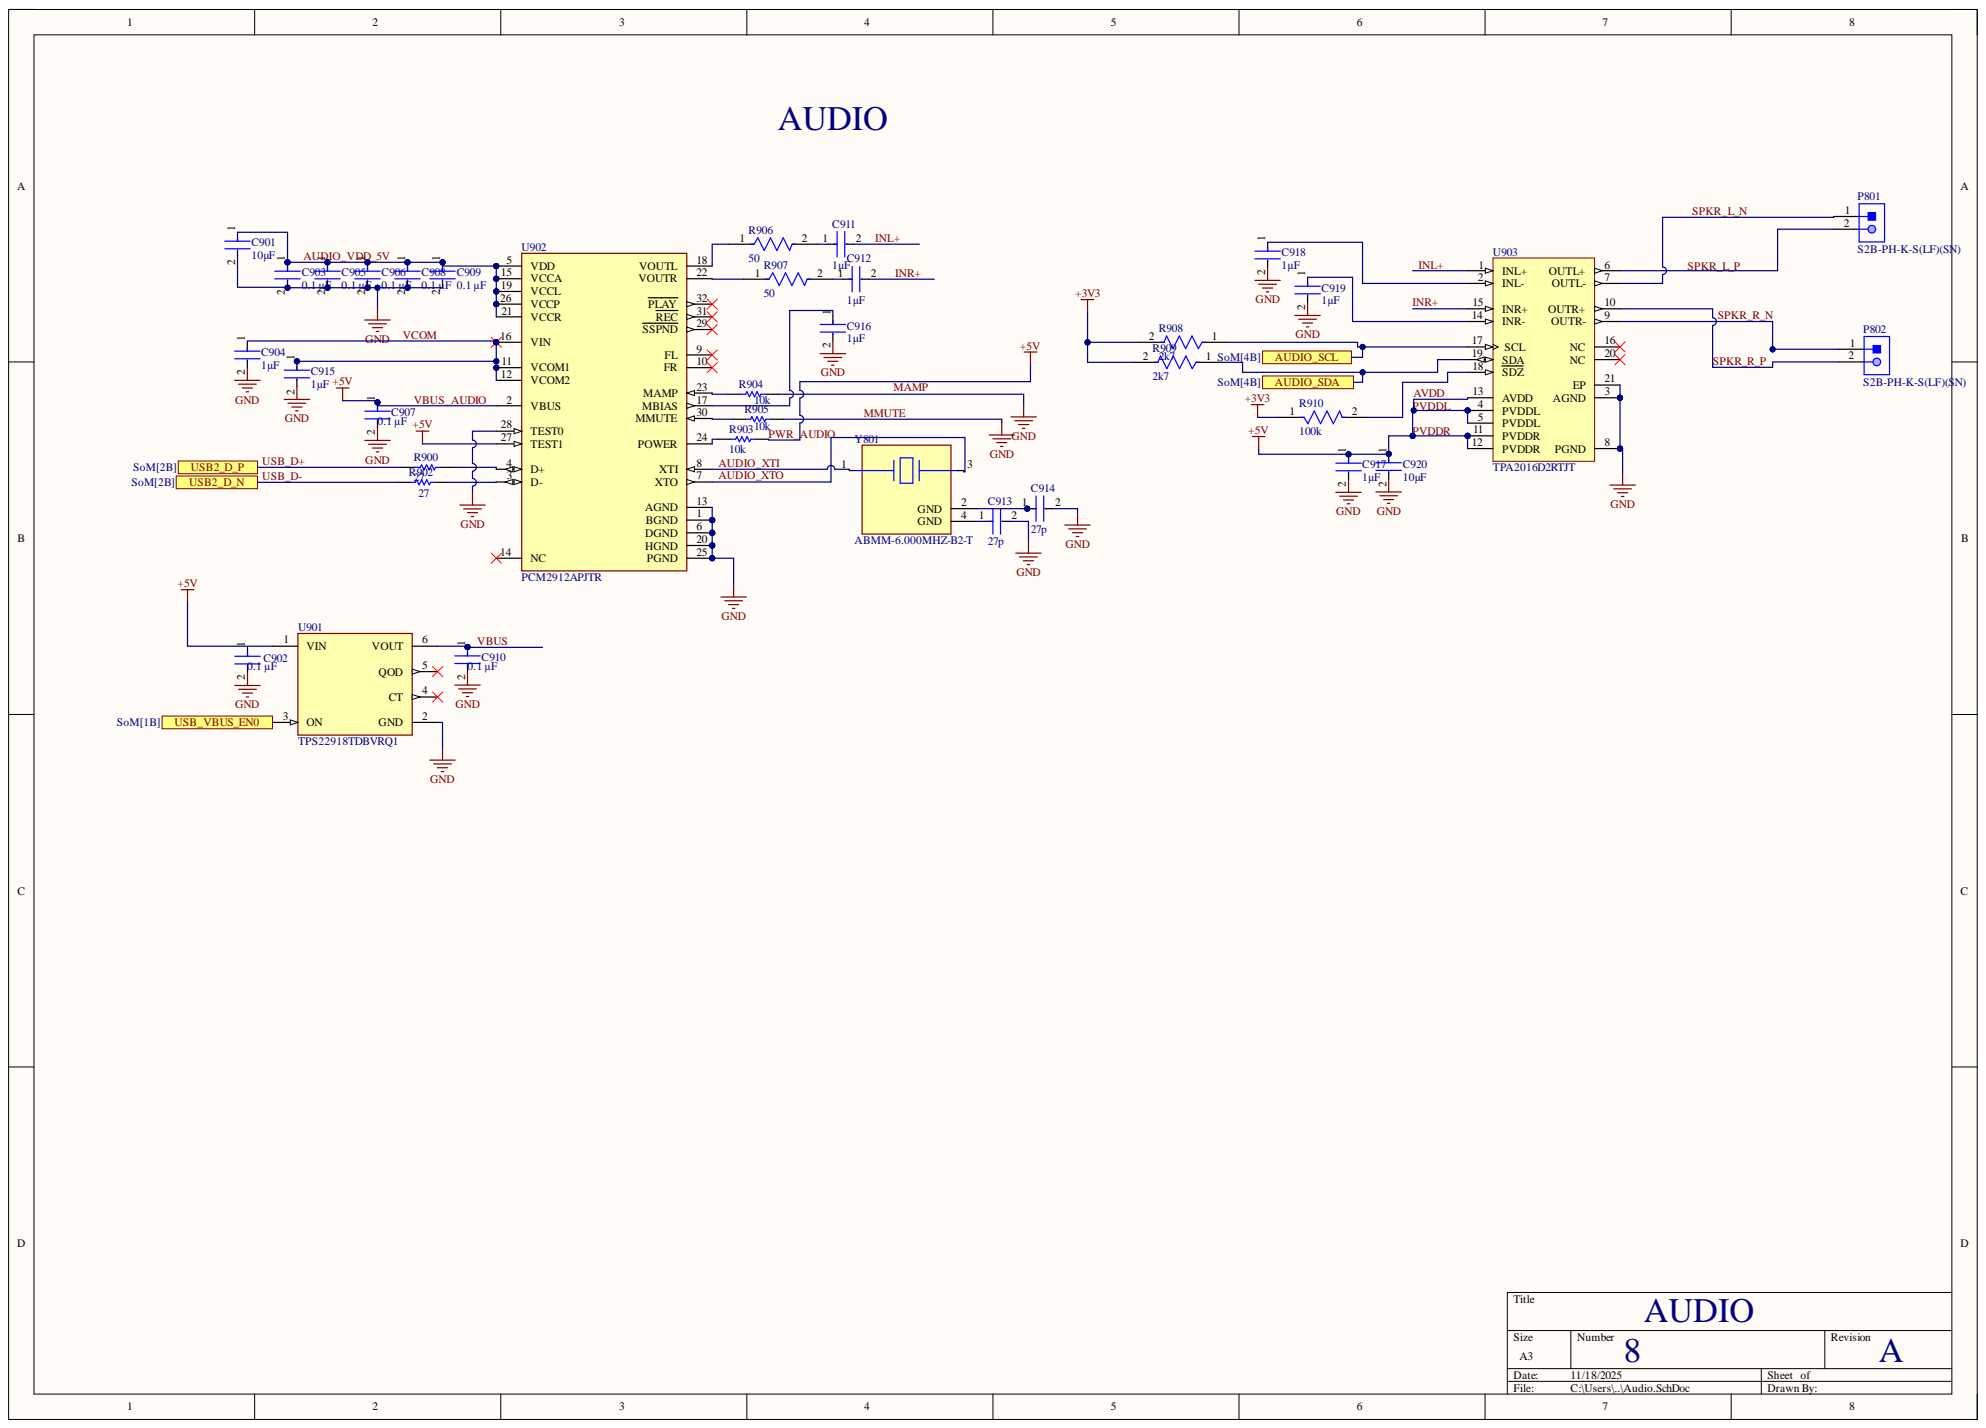
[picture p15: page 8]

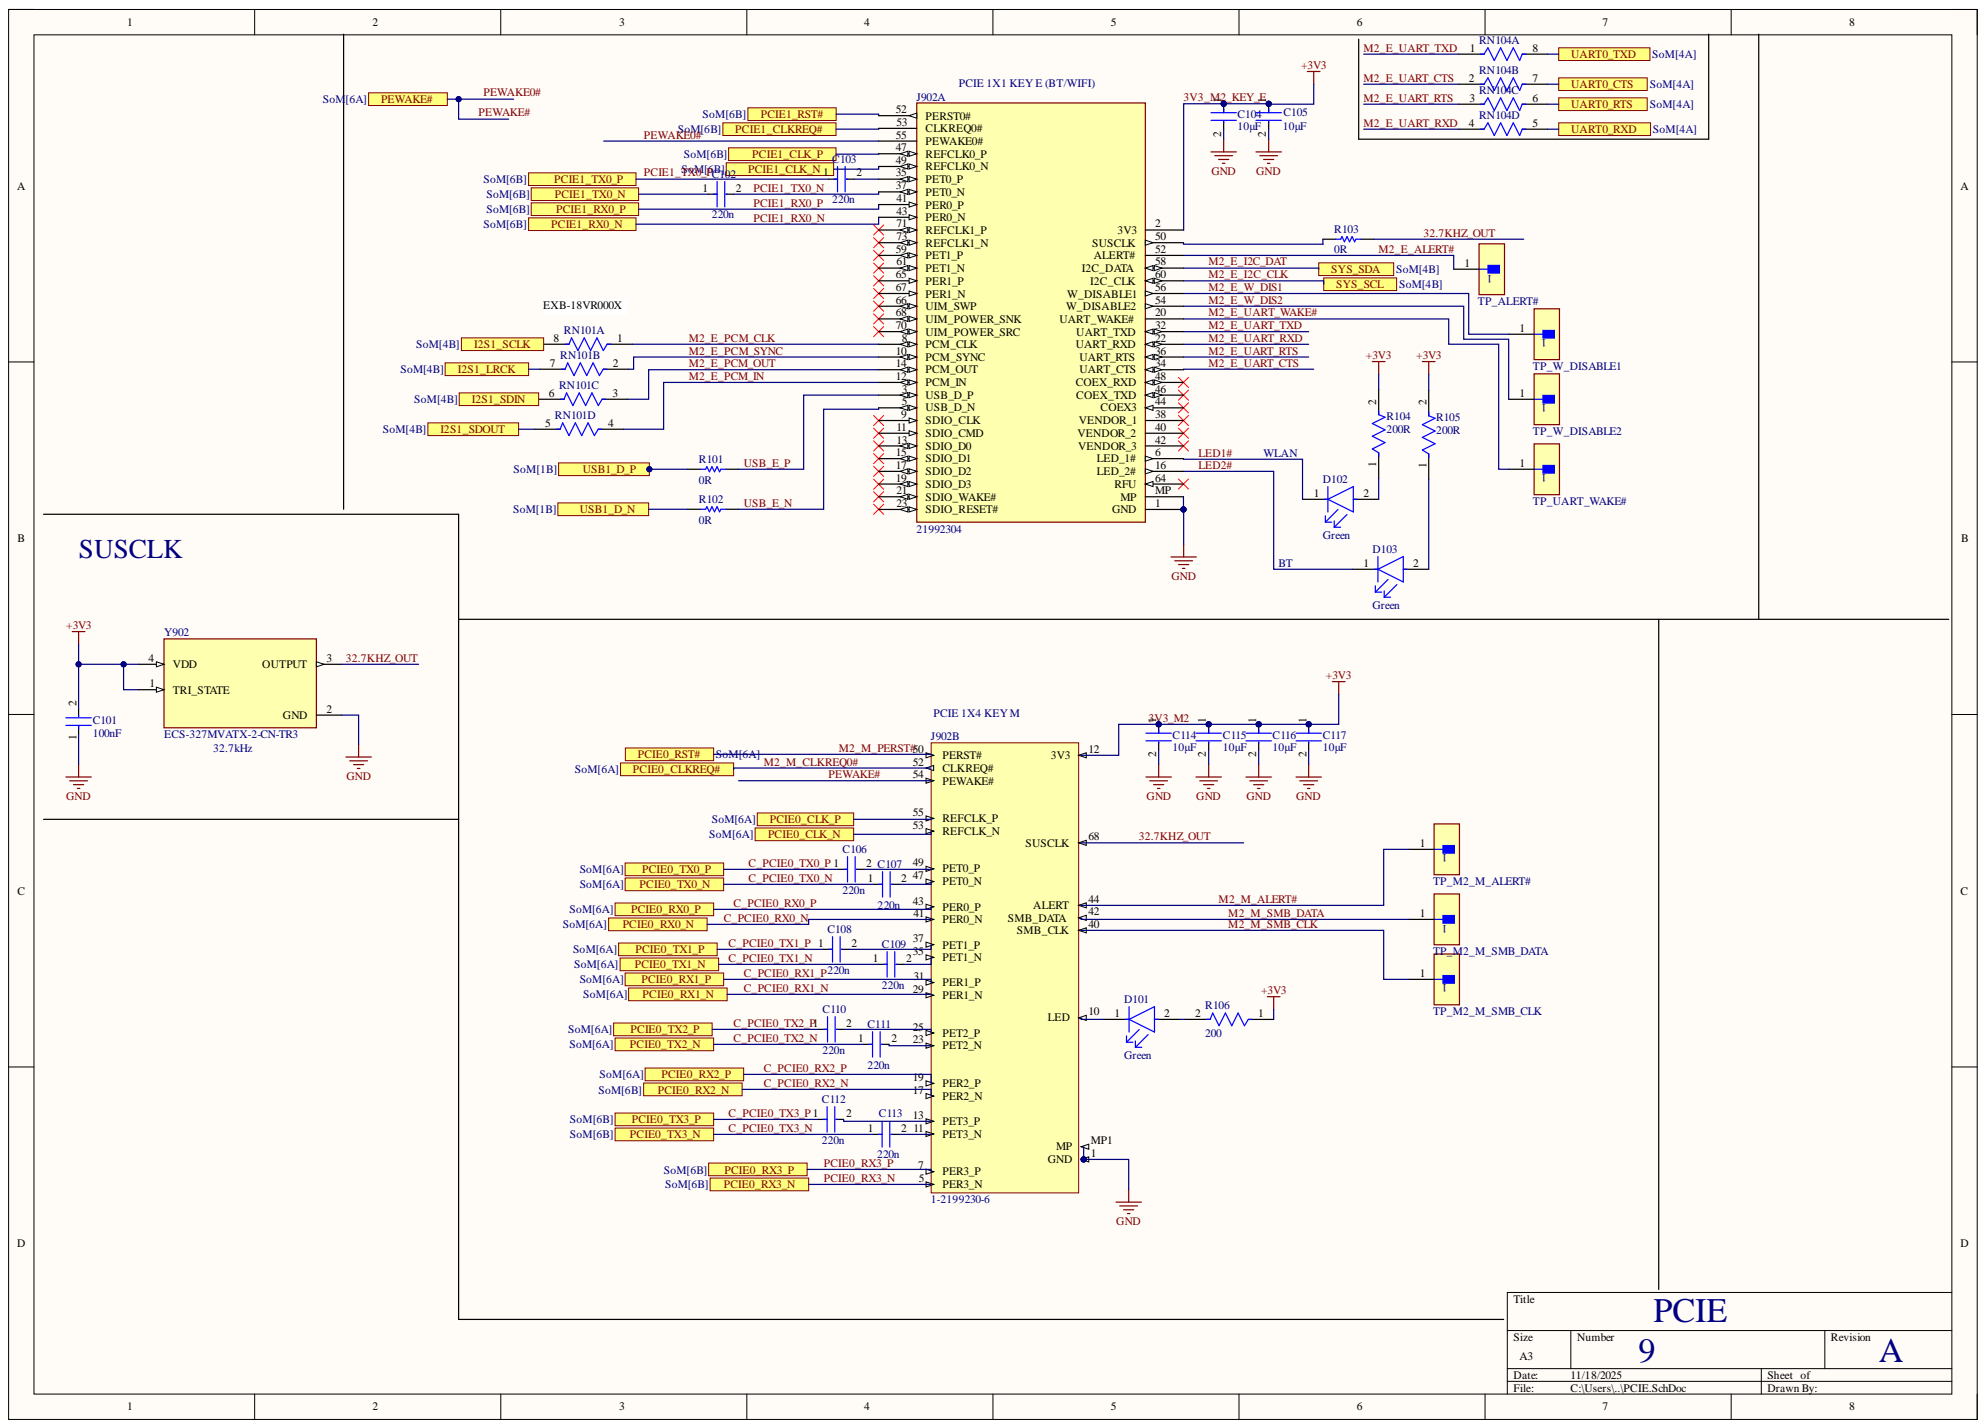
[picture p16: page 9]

PCIE 1X1 KEY E (BT/WIFI)

PCIE1_RX0_N | REFCLK1_P 71

PER1_N 67 | M2_E_W_DIS1 | SYS_SCL | SoM[4B] M2_E_I2C_CLK

M2_E_PCM_OUT | PCM_OUT 14 | M2_E_UART_CTS
M2_E_PCM_IN | PCM_IN 12

USB_D_P 3

USB_E_P | SDIO_CLK 9

USB_E_N | | SDIO_D3 19 | | Green

SDIO_D2 17 | | LED2#

PET1_P 37 | M2_M_SMB_CLK

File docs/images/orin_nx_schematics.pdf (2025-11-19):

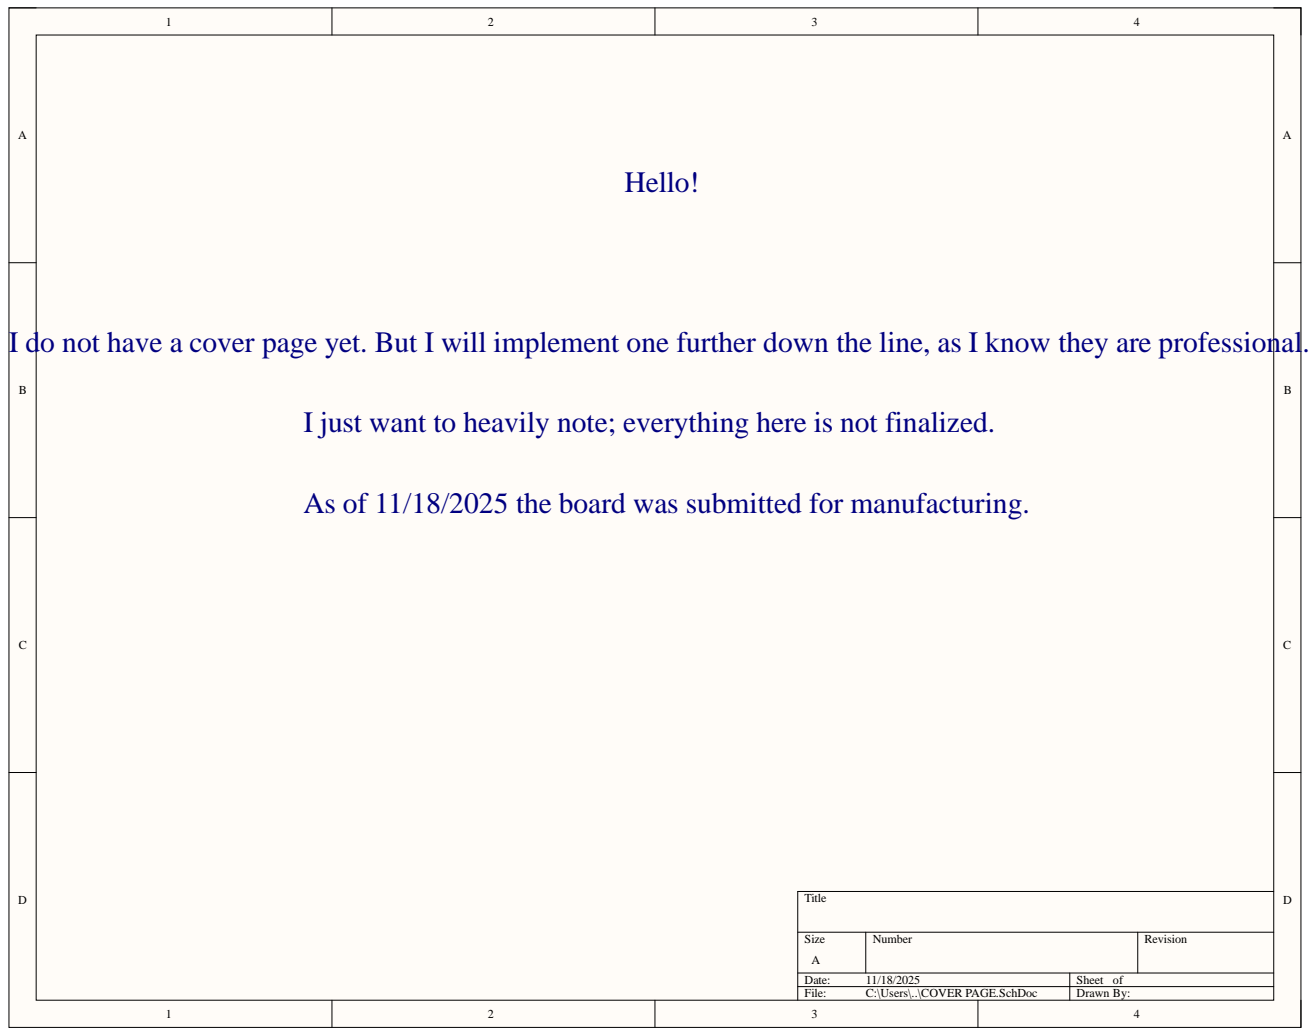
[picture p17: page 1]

I do not have a cover page yet. But I will implement one further down the line, as I know they are professional.

I just want to heavily note; everything here is not finalized.

As of 11/18/2025 the board was submitted for manufacturing.



BOOT 8

Size A4 | Number 3 | Revision A

Date: 11/18/2025 | Sheet of
File: C:\Users\..\eDP.SchDoc | Drawn By:


A 5
B 5

S S TXP 2 | S h e l l
S S TXN 2

4 E | QAR | Q 1

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


3V3_MODE2 | MODE2 20

SYS_IN1 | | EN 19


Short press- power on, long press- power off



PCIE 1X1 KEY E (BT/WIFI)

PCIE1_RX0_N | REFCLK1_P 71

PER1_N 67 | M2_E_W_DIS1 | SYS_SCL | SoM[4B] M2_E_I2C_CLK

M2_E_PCM_OUT | PCM_OUT 14 | M2_E_UART_CTS
M2_E_PCM_IN | PCM_IN 12

USB_D_P 3

USB_E_P | SDIO_CLK 9

USB_E_N | | SDIO_D3 19 | | Green

SDIO_D2 17 | | LED2#

PET1_P 37 | M2_M_SMB_CLK

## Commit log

2025-11-15 Add files via upload
    Add CarrierMotherboard outputs
    [Audio.SchDoc, Battery.SchDoc, COVER PAGE.SchDoc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]
2025-11-15 Remove duplicate root-level project output files
    [Audio.SchDoc, Battery.SchDoc, COVER PAGE.SchDoc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]
2025-11-18 Reorganize project: move Altium files into CarrierMotherboard folder and add fab/assembly PDFs, remove 6V dcdc, replace it with 5v -> 6v booster, remove 9V contract, replace it with 5v contract.
    [Audio.SchDoc, Battery.SchDoc, CarrierMotherboard.PrjPcb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]
2025-11-19 Added schematics and PCB images to docs; updated README
2025-11-19 Adjust schematics to be up to date
